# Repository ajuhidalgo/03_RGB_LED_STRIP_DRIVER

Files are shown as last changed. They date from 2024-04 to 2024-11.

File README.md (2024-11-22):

## Controlador de Tiras LED RGB con ESP32-C6-MINI
 

### Descripción
Este proyecto se centra en la creación de un controlador para tiras de LEDs RGB utilizando el microcontrolador **ESP32-C6-MINI**. El dispositivo está diseñado para ser compatible con **Google Home** y se conecta a través de **Wi-Fi**. El controlador permite seleccionar colores y efectos para las tiras LED.

### Componentes del Proyecto
1. **Circuito y PCB**: Diseñé el circuito y el PCB para el controlador utilizando **KiCad**. Puedes encontrar los esquemas y archivos Gerber en este repositorio.
2. **Carcasa**: Creé una carcasa en 3D para proteger el controlador con el programa **Fusion 360**. Los archivos STL y los detalles de impresión están disponibles en la carpeta de mecánica.
3. **Firmware**: El código fuente del firmware se encuentra en el repositorio. En la memoria del proyecto puedes obtener información acerca de la configuración.

### Características Clave
- **Microcontrolador**: Utilizamos el módulo **ESP32-C6-MINI** de Espressif Systems y transistores **mosfet** para controlar las tiras LED.
- **Interfaz de uso**: El dispositivo se controla a través del entorno **Google Home**. Permite la integración con la domótica del hogar, programar horarios de encendido o programar escenas. Esto lo conseguimos gracias al uso de la plataforma Sinric Pro.
- **Selección de Colores**: Los usuarios pueden elegir entre una amplia gama de colores para personalizar las tiras LED.

### Repositorio en GitHub
Puedes encontrar el código fuente, los esquemas, los archivos de Gerber, los archivos STL y más en este repositorio.

¡Buena suerte con tu proyecto! Si tienes alguna pregunta o necesitas más detalles, puedes ponerte en contacto conmigo.

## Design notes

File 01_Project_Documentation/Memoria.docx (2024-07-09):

DISEÑO DE UN CONTROLADOR IOT PARA TIRAS LED RGB

Autor: Juan Antonio Hidalgo Torres.

Fecha: 27/04/2024

# INDICE

# INDICE DE FIGURAS

# 1. INTRODUCCIÓN

En los últimos años, se ha incrementado considerablemente el número de dispositivos y objetos cotidianos que tienen acceso a internet, lo que ha dado lugar a lo que llamamos IoT. “Internet of things” es un concepto que hace referencia a la interconexión de dispositivos cotidianos a través de internet, lo que les permite comunicarse, recopilar datos o realizar acciones de forma inteligente en base a los datos recopilados. Todo esto tiene como principales beneficios la mejora en la eficiencia, la comodidad y la automatización en la vida cotidiana.

En la actualidad el IoT tiene muchísimas aplicaciones, como por ejemplo, en el campo de la salud, en el que cada vez se crean más dispositivos capaces de monitorizar constantes, llevar a cabo seguimientos de actividad y crear alertas. Por otro lado, en el mundo de la agricultura tambien podemos encontrar aplicaciones, como el monitoreo de cultivos, el riego automático o el seguimiento de ganado. Además, existen muchos más ámbitos a los que ha llegado el IoT, pero en concreto, es en la domótica donde más se ha desarrollado. Esto se debe a que ha permitido controlar de forma inteligente todo tipo de dispositivos del hogar, como cerraduras, persianas, luces, termostatos, cámaras de seguridad y todo tipo de electrodomésticos.

En dispositivos como luces, y aún más en luces RGB, tener conexión y control a través de internet nos puede aportar numerosos aspectos positivos. En concreto, podremos programar horarios de encendido y apagado, programar diferentes escenas, controlar los colores, prescindir de mandos a distancia o actuar con comandos de voz con la ayuda de plataformas como Home Assistant.

Es por esto, por lo que en este proyecto, crearemos un dispositivo capaz de llevar a cabo todas las acciones anteriormente descritas, y que sea compatible con el entorno de Google Home.

Este proyecto surge a partir de la iniciativa personal de desarrollar un proyecto “open source”, con la intención de compartir de forma libre el trabajo realizado. Y, de este modo, devolver a la comunidad de hardware libre parte del conocimiento adquirido a lo largo de los años. Por otra parte, surge de la meta personal de crear un dispositivo que permita controlar las luces decorativas de una forma sencilla, sin mandos a distancia y conectado a internet. Aunque ya existen dispositivos como este en el mercado con un precio accesible, creo que el valor de un proyecto de estas características reside en el aprendizaje que se puede lograr en el proceso y en la satisfacción personal de crear un producto desde cero.

# 2. OBJETIVOS DEL PROYECTO

Como objetivo principal del proyecto, planteamos crear un dispositivo que permita controlar tiras led RGB de forma remota y a través de internet.

Para el desarrollo del objetivo principal descrito anteriormente, se plantean los siguientes objetivos secundarios:

- Diseño y fabricación de un PCB que permita controlar la tira led RGB. Nos permitirá el encendido y el apagado de la tira, modificar el color y modificar el brillo de la luz que emite. Además, tendrá la capacidad de conectarse a internet mediante Wi-Fi.
- Diseño y fabricación de una carcasa para envolver el PCB.
- Desarrollo del software del dispositivo.
- Integración del dispositivo con el entorno de Google Home.

# 3. DESCRIPCIÓN DEL SISTEMA

Como se puede ver en la siguiente imagen, el sistema completo está formado por un total de tres bloques principales: Google home, Sinric Pro, el circuito físico del controlador o PCB, y el firmware encargado de controlar a este.

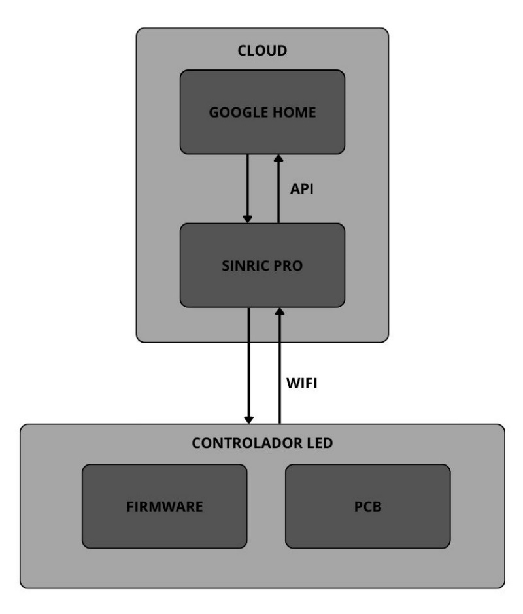
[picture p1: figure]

## 3.1 PCB.

Por un lado, encontramos el PCB objeto de diseño en este proyecto, en el que encontraremos un microcontrolador, los transistores necesarios para controlar cada canal de la tira, y los componentes necesarios para la fase de alimentación:

- Microcontrolador ESP32-C6 Mini para un procesamiento potente con un reducido tamaño y bajo consumo. Además, nos permite la conexión Wi-Fi y Bluetooth.
- Tres transistores MOSFETs FDD8880 para un control preciso de cada canal de las tiras de LED.
- Regulador de voltaje AMS1117CD para convertir la alimentación de entrada de 12V a un voltaje estable de 3.3V para el ESP32-C6 Mini y otros componentes.
- Componentes pasivos adicionales para completar el circuito y garantizar un funcionamiento óptimo.

El ESP32-C6 Mini envía a los MOSFETs señales PWM (Pulse Width Modulation) para modular la intensidad de cada uno de los tres canales de las tiras de LED con precisión. El regulador de voltaje asegura un voltaje estable 3.3V para el ESP32-C6 Mini y el resto de las componentes del circuito lógico.

## 3.2 FIRMWARE.

El firmware programado para el microcontrolador ESP32-C6 Mini, usando el framework de Arduino y el entorno de PlatformIO en Visual Studio Code, permite la gestión del hardware de potencia. Además, se encarga de las comunicaciones con el intermediario Sinric Pro y el ecosistema de domótica Google Home.

En concreto, el firmware se encarga de las siguientes tareas

- Recibir comandos de la aplicación Google Home a través de Sinric Pro.
- Interpretar los comandos de forma precisa y generar las señales PWM adecuadas para controlar los MOSFETs.
- Monitorear el estado de las tiras de LED.
- Enviar información de estado y actualizaciones a la aplicación Google Home, a través de Sinric Pro, para mantener una sincronización completa.

## 3.3 SINRIC PRO.

Sinric Pro es una plataforma de IoT (Internet de las Cosas) que permite conectar dispositivos IoT a los asistentes de voz Alexa y Google Home. Actúa como intermediario entre la aplicación Google Home y el firmware del ESP32-C6 Mini, facilitando la comunicación entre ambos. De esta forma, no será necesario programar una API que lleve a cabo este trabajo.

Como ventajas principales encontramos las siguientes:

- Conexión segura y robusta: Utiliza una conexión directa con los servidores de Amazon y Google para una experiencia más estable.
- Compatibilidad amplia: Soporta todos los tipos de dispositivos IoT, incluyendo luces, interruptores, cerraduras, termostatos, sensores, etc.
- Fácil de usar: Configuración sencilla y gratuita a través de una interfaz web de usuario.
- Desarrollo flexible: Ofrece bibliotecas Python, C++ y Arduino con ejemplos para crear aplicaciones IoT personalizadas.

## 3.4 GOOGLE HOME.

La aplicación Google Home ofrece una interfaz de usuario intuitiva y fácil de usar para controlar las tiras de LED de forma remota desde una app o desde la web. De este modo, no tendremos que llevar a cabo el trabajo de crear nuestra propia interfaz, y podremos aprovechar el sistema de Google. Esto nos permite una mayor usabilidad e integración con el sistema domótico ya existente.

La interfaz de usuario nos facilita las siguientes acciones:

- Encender y apagar las luces de forma simple desde la app y con comandos de voz a través del asistente.
- Ajustar la intensidad de las luces.
- Seleccionar el color de las luces.
- Crear escenas de iluminación personalizadas.

# 4. DISEÑO DEL SISTEMA

# 5. PROTOTIPO

# 6. RESULTADOS

# 7. CONCLUSIONES

Diseño de un controlador IoT para tiras led RGB Juan Antonio Hidalgo Torres

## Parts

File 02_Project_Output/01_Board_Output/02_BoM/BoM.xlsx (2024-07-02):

Manufacter | Manufacter Part Number | Description | References | Quantity | URL
Samsung Electro-Mechanics | CL10E104KC8VPNC | CAP CER 100NF 100V X8L 0603 | C1 | 2 | https://www.digikey.es/es/products/detail/samsung-electro-mechanics/CL10E104KC8VPNC/20498486
YAGEO | CC0603KRX7R7BB105 | CAP CER 1UF 16V X7R 0603 | C2, C3 | 2 | https://www.digikey.es/es/products/detail/yageo/CC0603KRX7R7BB105/2833611
YAGEO | RC0603FR-0710KL | RES 10K OHM 1% 1/10W 0603 | R1, R2, R3, R4, R5, R6 | 7 | https://www.digikey.es/es/products/detail/yageo/RC0603FR-0710KL/726880
Vishay General Semiconductor | DF04S-E3/77 | BRIDGE RECT 1PHASE 400V 1A DFS | D1 | 1 | https://www.digikey.es/es/products/detail/vishay-general-semiconductor-diodes-division/DF04S-E3-77/2143841
Espressif Systems | ESP32-C6-MINI-1-N4 | RF TXRX MODULE BT PCB TRACE SMD | IC1 | 1 | https://www.digikey.es/es/products/detail/espressif-systems/ESP32-C6-MINI-1-N4/17885796
UMW | AMS1117CD-3.3 | IC LDO REG 3.3V 1A TO252 | U1 | 1 | https://www.digikey.es/es/products/detail/umw/AMS1117CD-3-3/17635272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
Onsemi | FDD8880 | MOSFET N-CH 30V 13A/58A TO252AA | Q1, Q2, Q3 | 3 | https://www.digikey.es/es/products/detail/onsemi/FDD8880/979930
Omron Electronics | B3U-1000P | SWITCH TACTILE SPST-NO 0.05A 12V | S1, S2 | 2 | https://www.digikey.es/es/products/detail/omron-electronics-inc-emc-div/B3U-1000P/1534338
CUI Devices | PJ-102A | CONN PWR JACK 2X5.5MM SOLDER | J1 | 1 | https://www.digikey.es/es/products/detail/cui-devices/PJ-102A/275425
JST Sales America | S4B-XH-A | CONN HEADER R/A 4POS 2.5MM | J2 | 1 | https://www.digikey.es/es/products/detail/jst-sales-america-inc/S4B-XH-A/1651041
Würth Elektronik | 61300411121 | CONN HEADER VERT 4POS 2.54MM | J3 | 1 | https://www.digikey.es/es/products/detail/w%C3%BCrth-elektronik/61300411121/4846827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

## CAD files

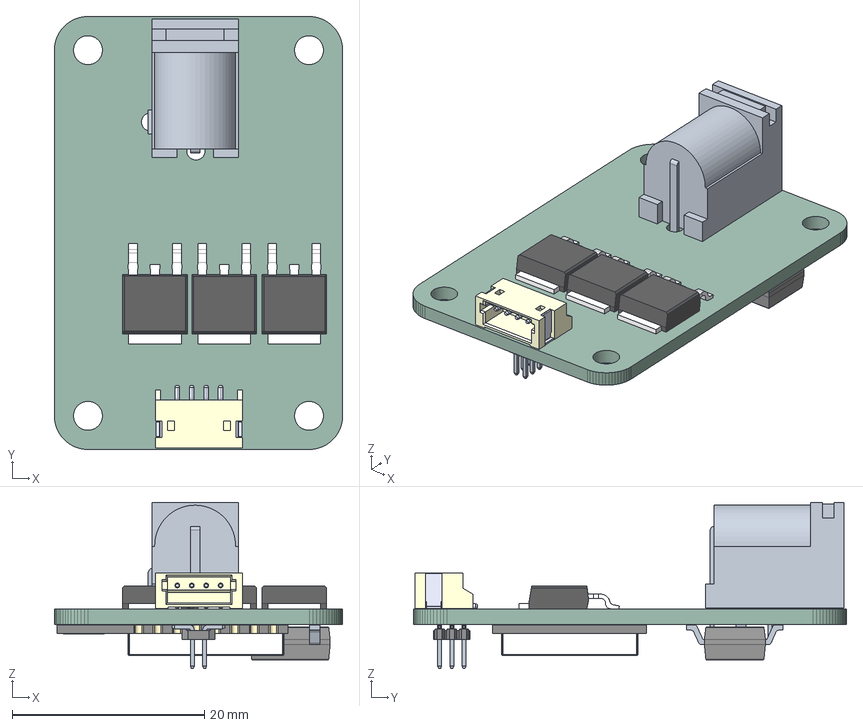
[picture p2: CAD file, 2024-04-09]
02_Project_Output/01_Board_Output/05_ExportSTEP/DriverRGB_v2.step
30.0 x 45.0 x 17.3 mm
DriverRGB_v2 PCB

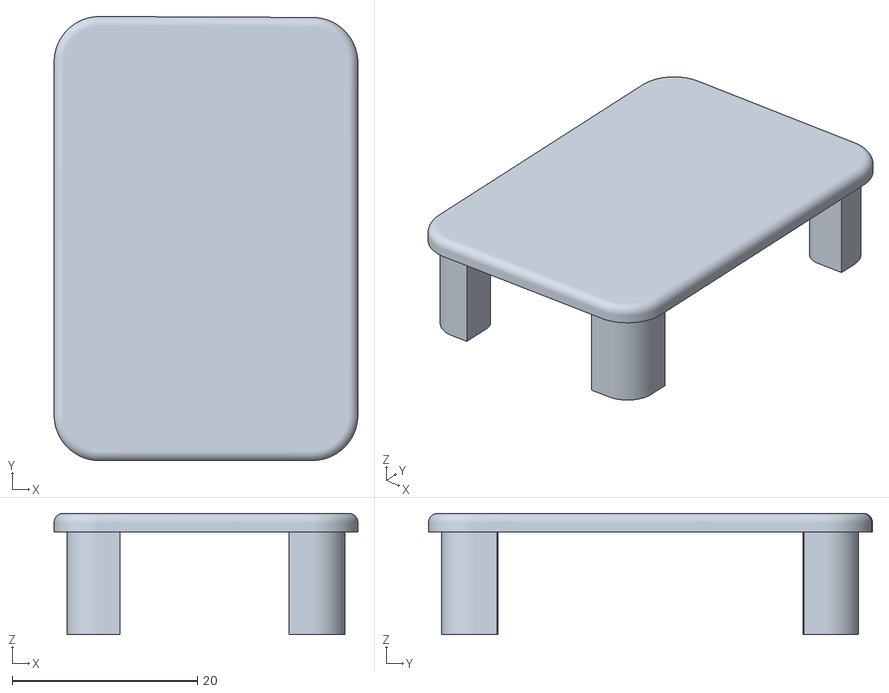
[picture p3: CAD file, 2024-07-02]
02_Project_Output/02_Mechanical_Ouput/Driver_Case_Top.stl
32.8 x 47.9 x 13.1

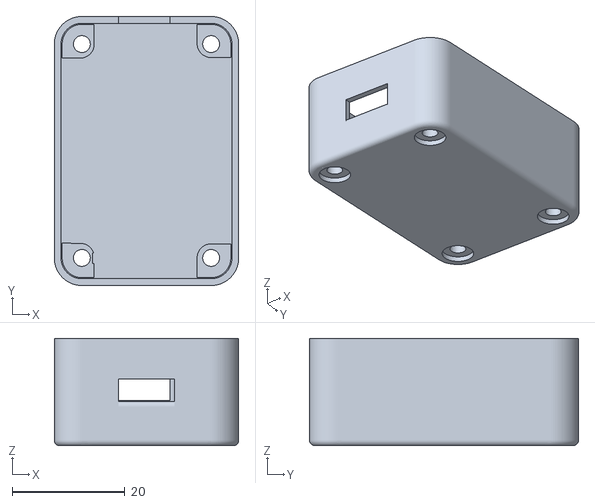
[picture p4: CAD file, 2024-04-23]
05_Mechanical_Desing/Driver_Case_Bottom.stl
32.8 x 47.8 x 19.1

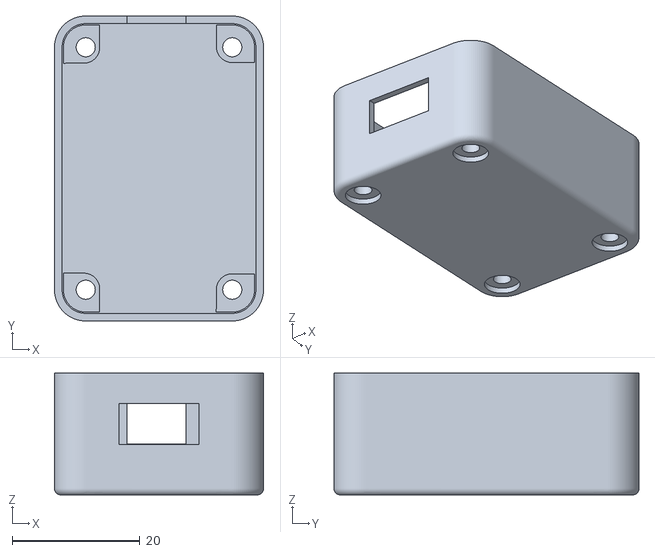
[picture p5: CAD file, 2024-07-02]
02_Project_Output/02_Mechanical_Ouput/Driver_Case_Bottom.stl
32.8 x 47.8 x 19.1

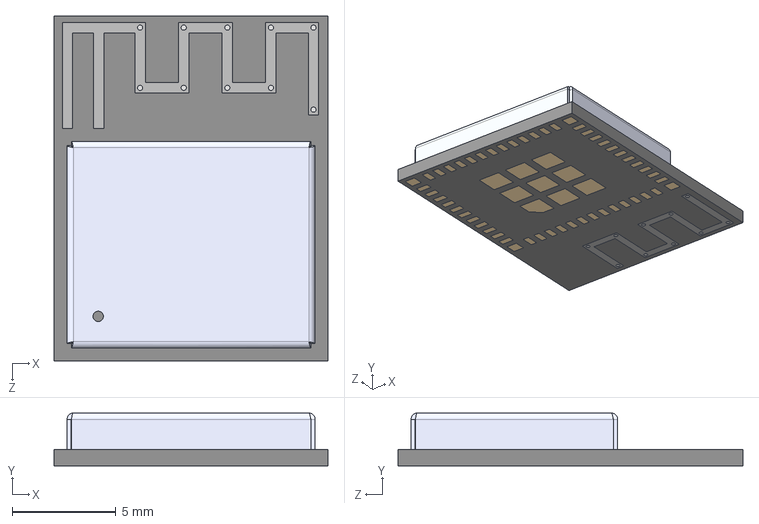
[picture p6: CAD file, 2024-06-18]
03_Boards/02_Libraries/03_3D/ESP32-C6-MINI-1-N4.STEP
13.2 x 2.55 x 16.6 mm

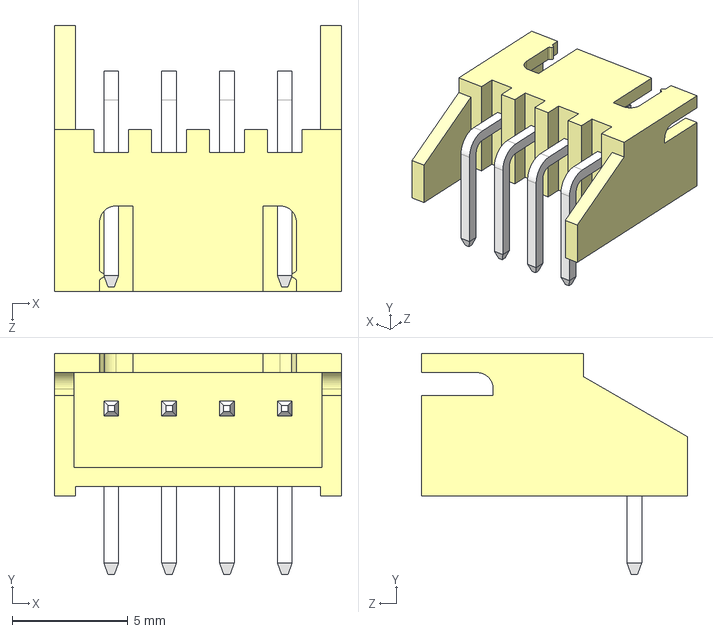
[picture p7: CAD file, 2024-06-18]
03_Boards/02_Libraries/03_3D/S4B-XH-A_LF__SN_.step
12.4 x 9.55 x 11.5 mm

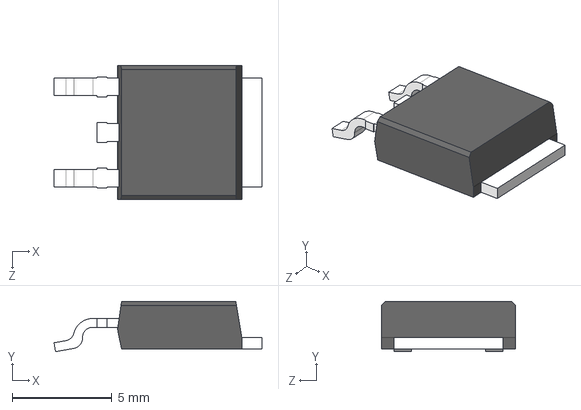
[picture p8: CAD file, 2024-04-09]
03_Boards/02_Libraries/03_3D/FDD8880.stp
10.4 x 2.52 x 6.73 mm

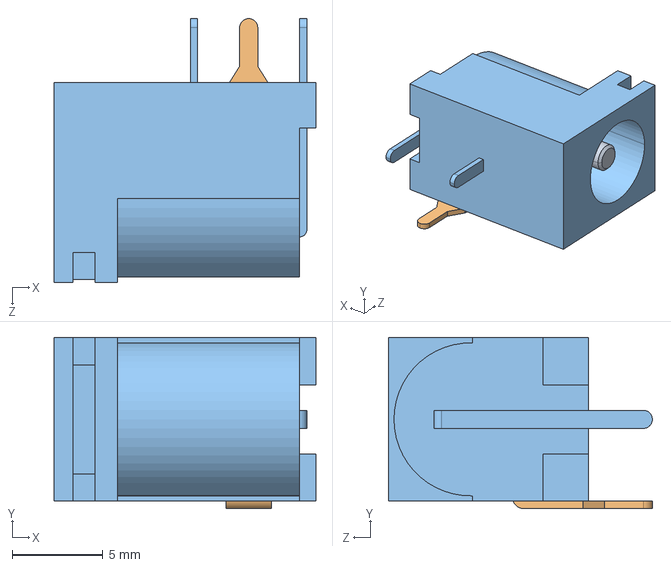
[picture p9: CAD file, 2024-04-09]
03_Boards/02_Libraries/03_3D/PJ-102A.stp
14.4 x 9.40 x 14.5 mm

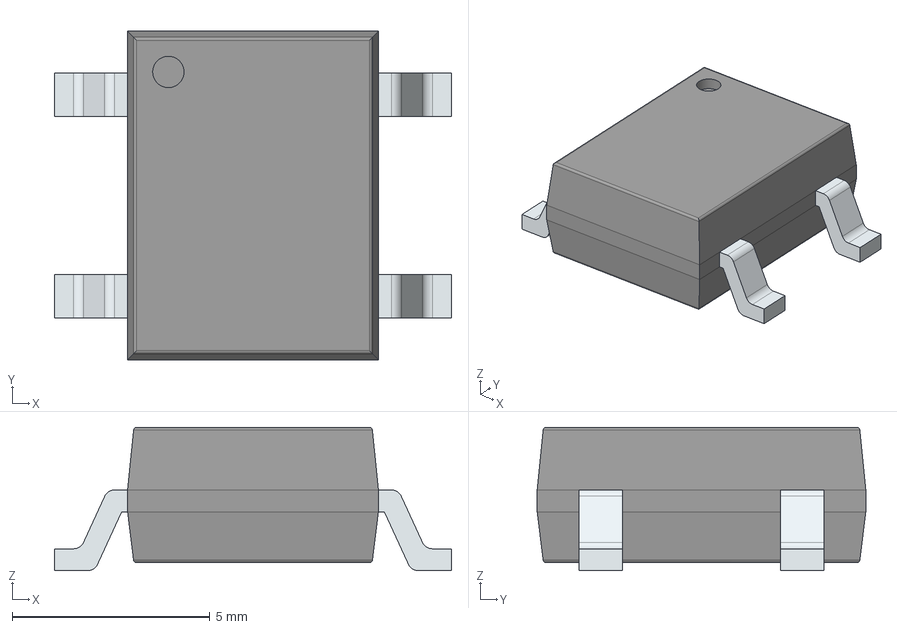
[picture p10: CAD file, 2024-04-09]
03_Boards/02_Libraries/03_3D/DF04S-E3_77.stp
10.1 x 8.32 x 3.63 mm
PinsArrayLR

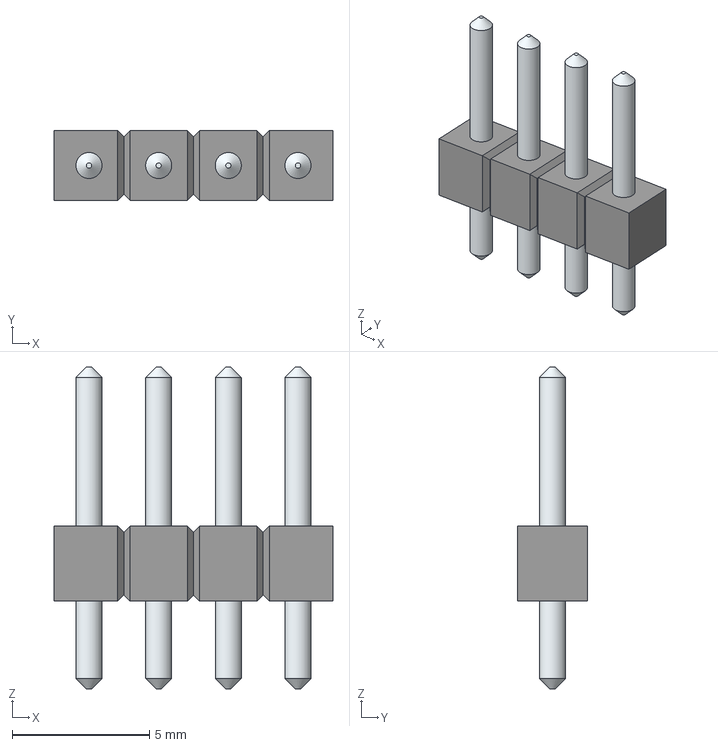
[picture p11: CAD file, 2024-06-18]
03_Boards/02_Libraries/03_3D/61300411121.stp
10.2 x 2.54 x 11.7 mm
LeadsArray

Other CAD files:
05_Mechanical_Desing/Driver_Case_Top.stl

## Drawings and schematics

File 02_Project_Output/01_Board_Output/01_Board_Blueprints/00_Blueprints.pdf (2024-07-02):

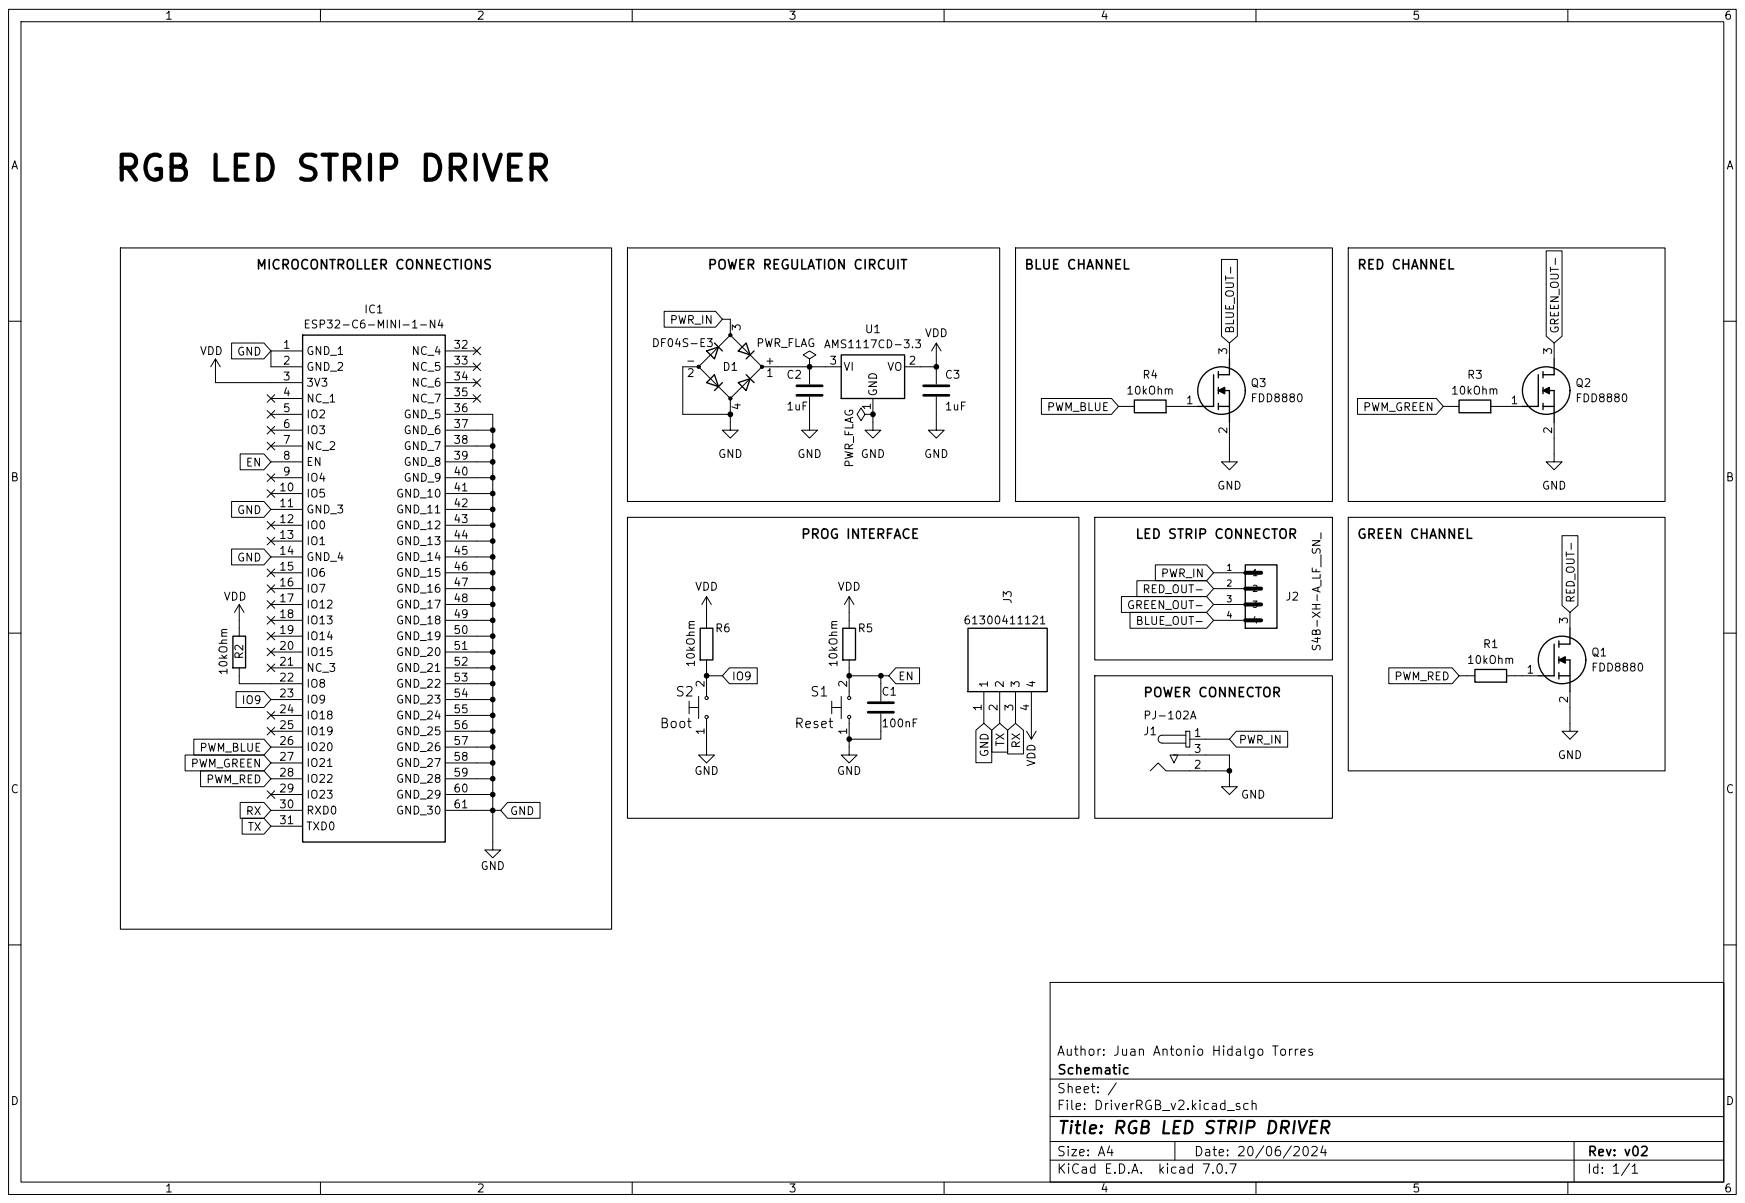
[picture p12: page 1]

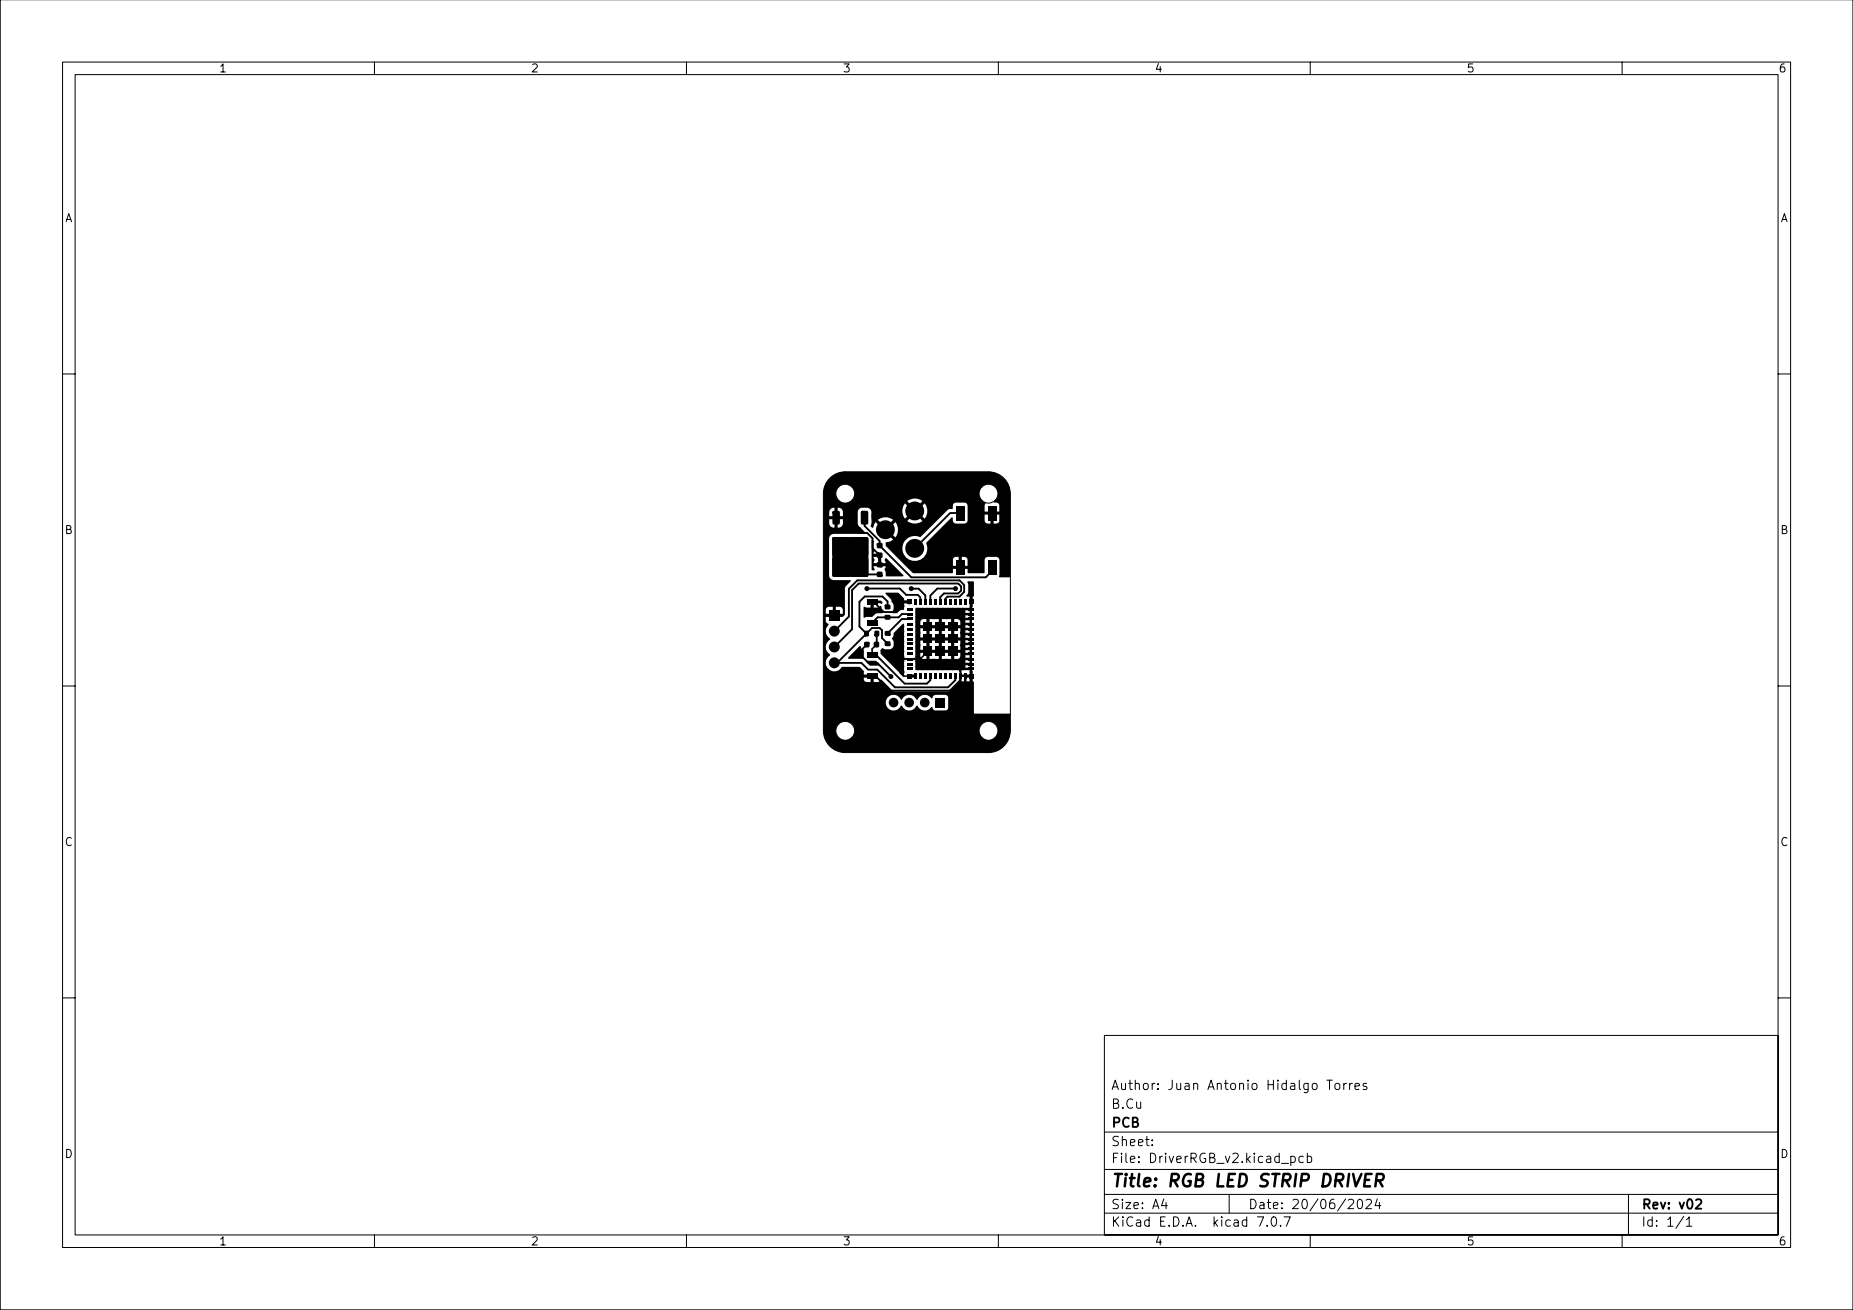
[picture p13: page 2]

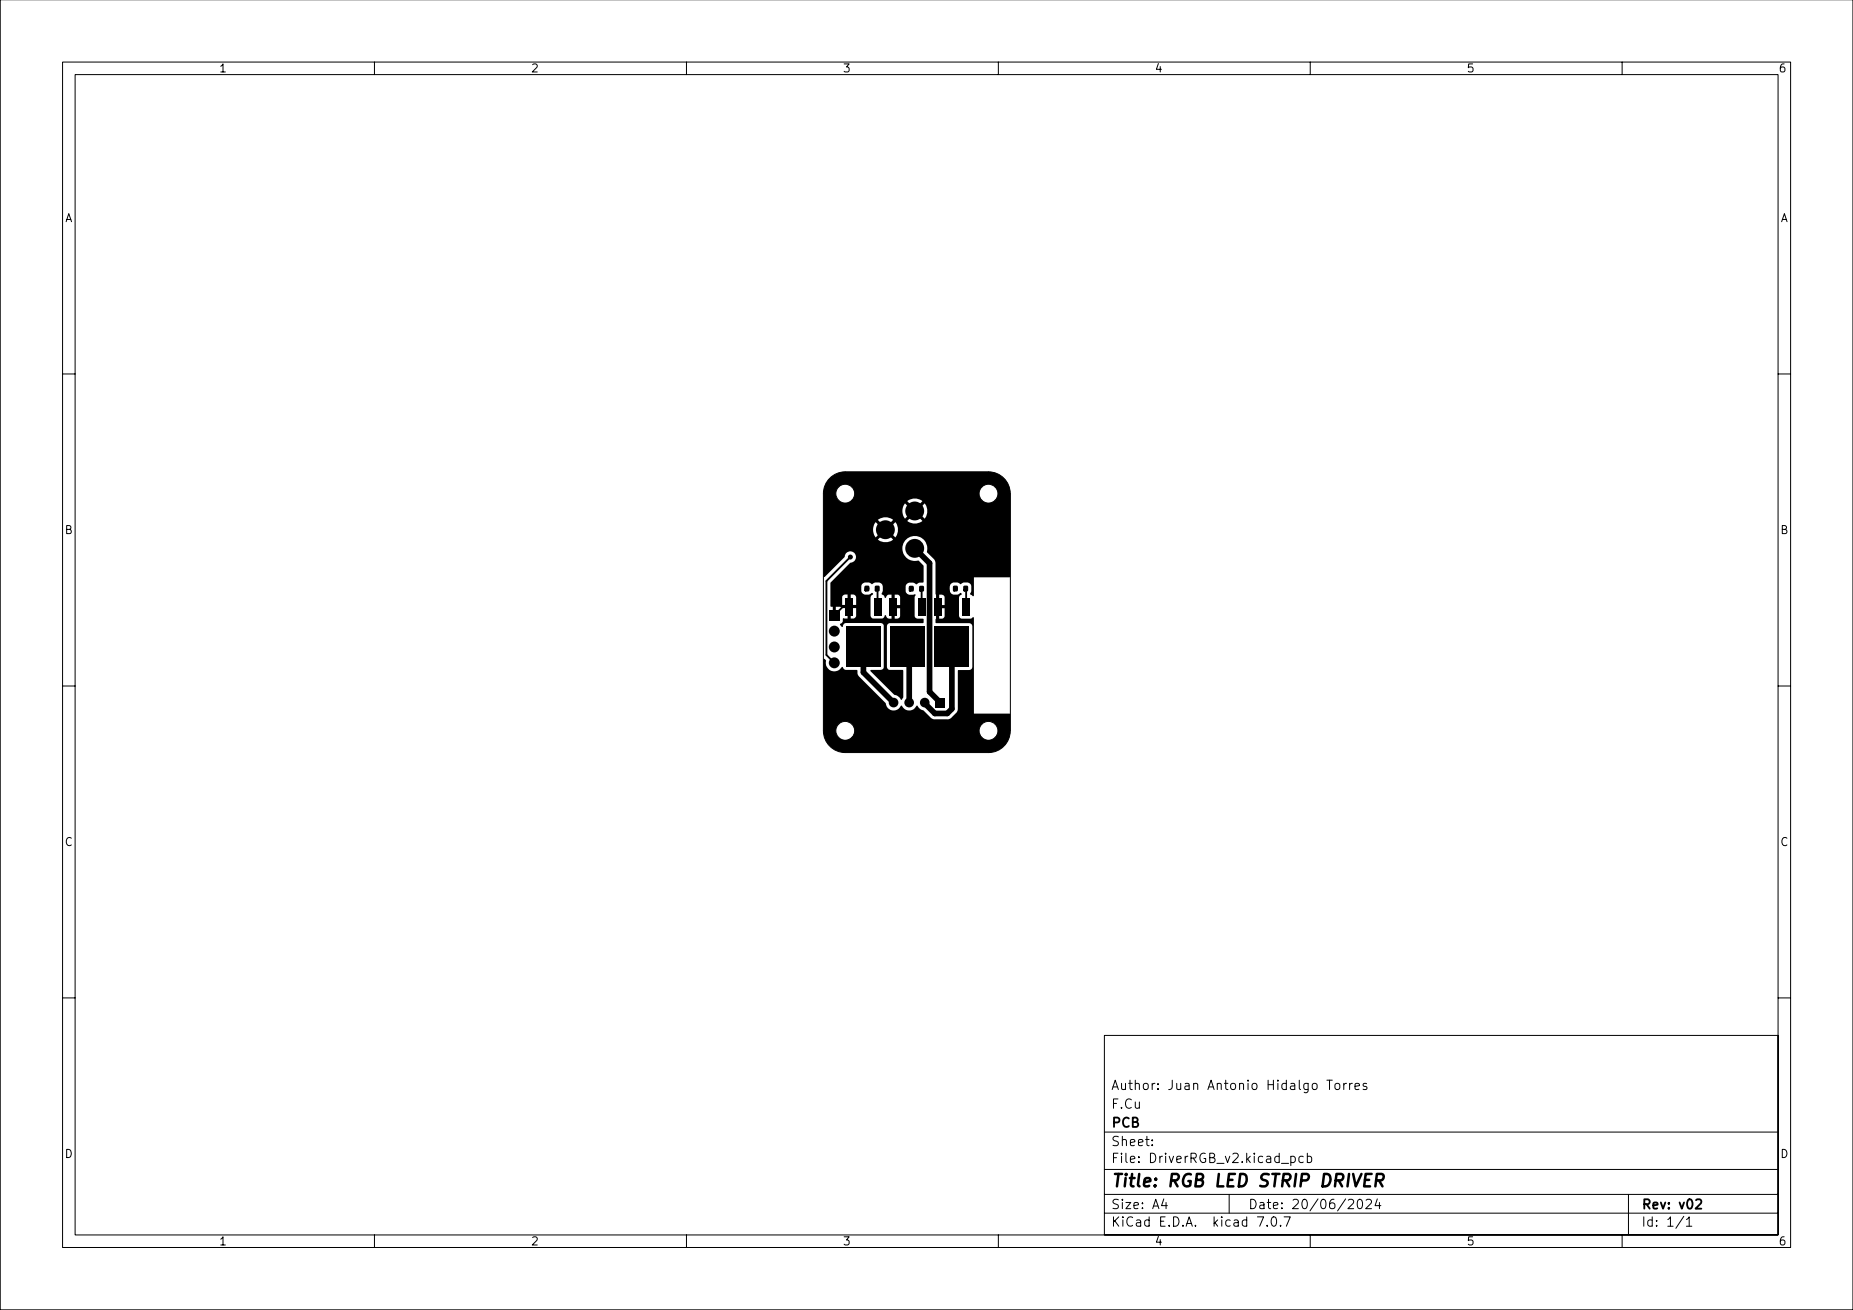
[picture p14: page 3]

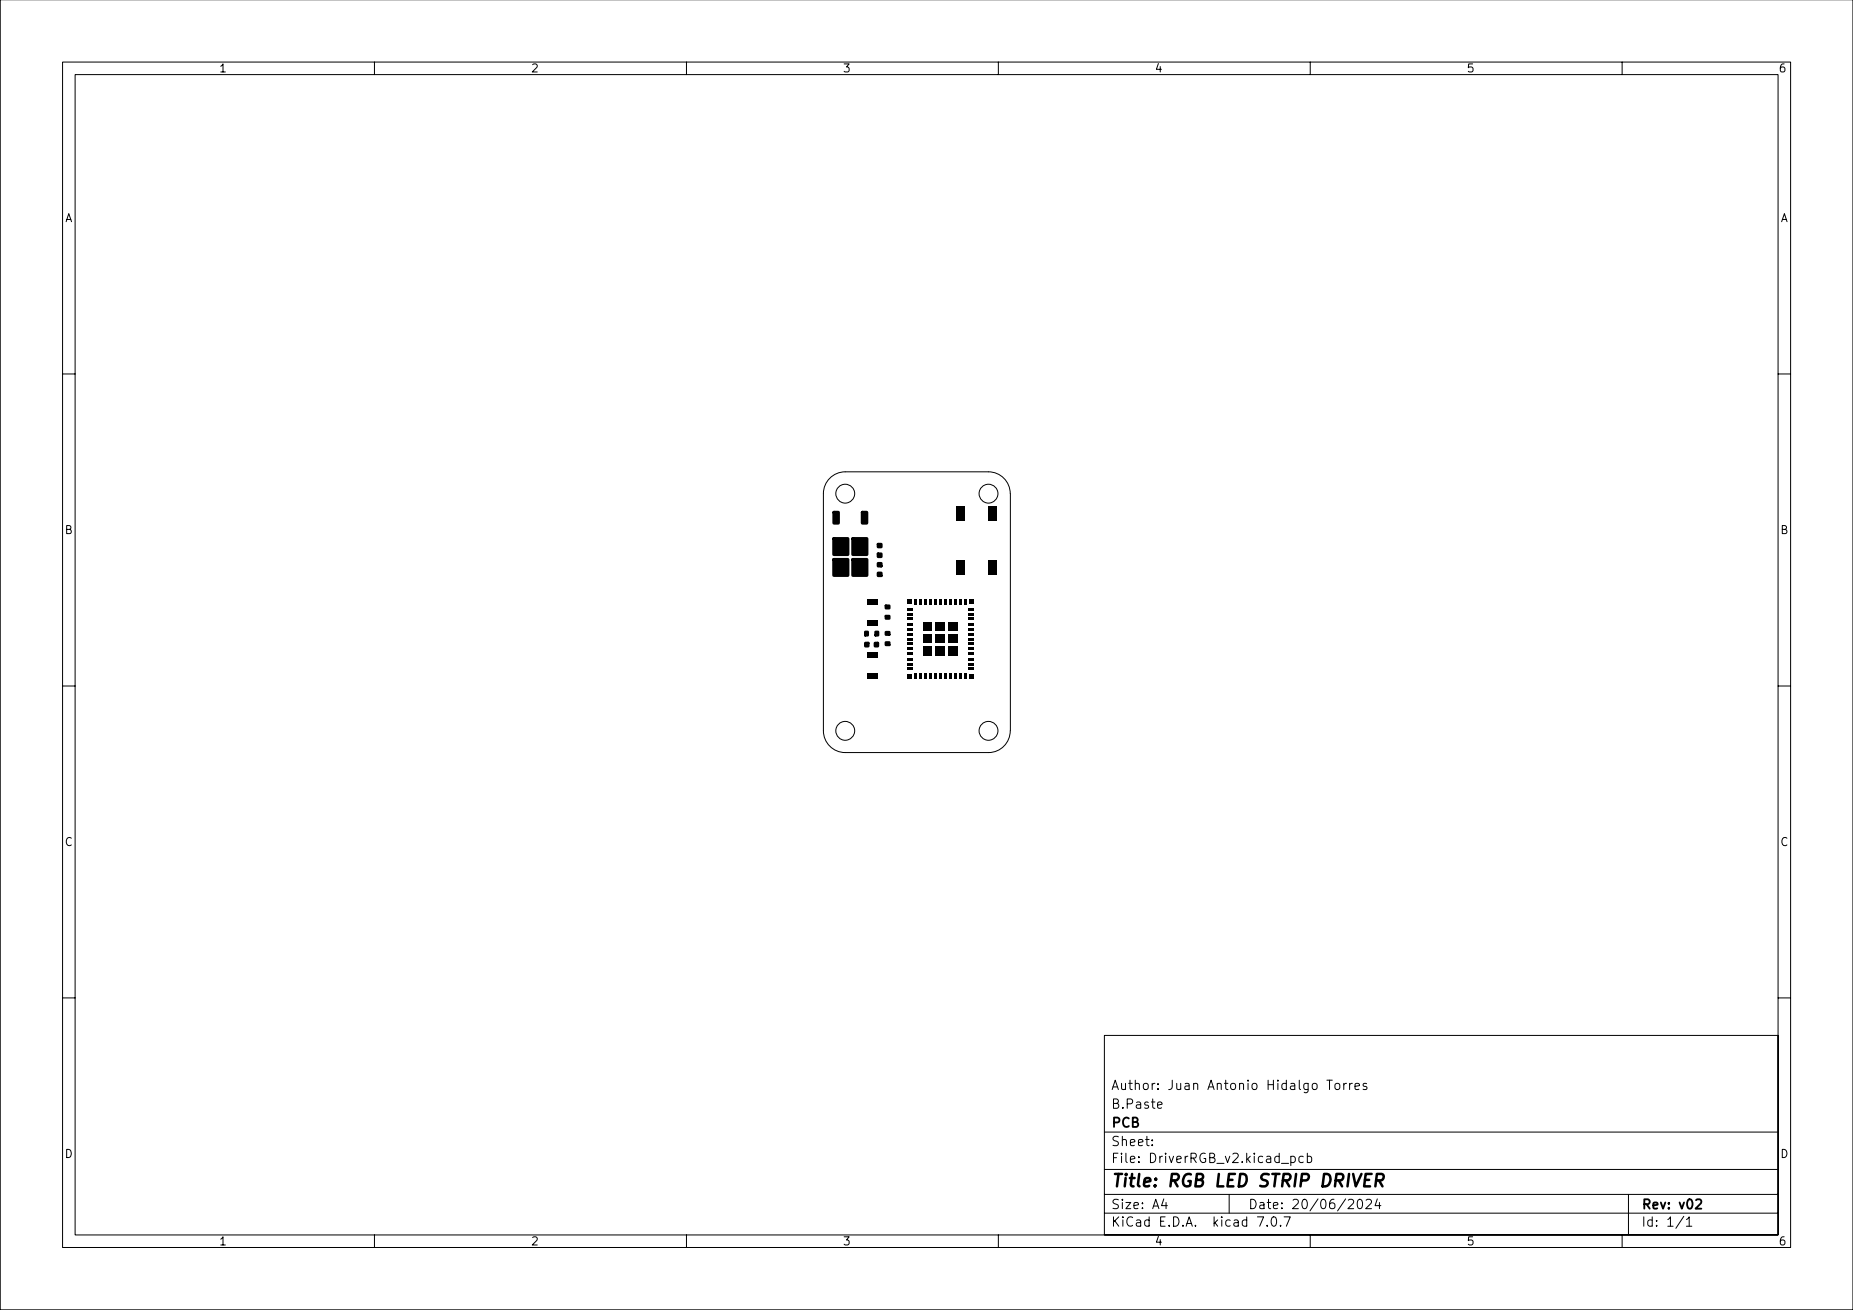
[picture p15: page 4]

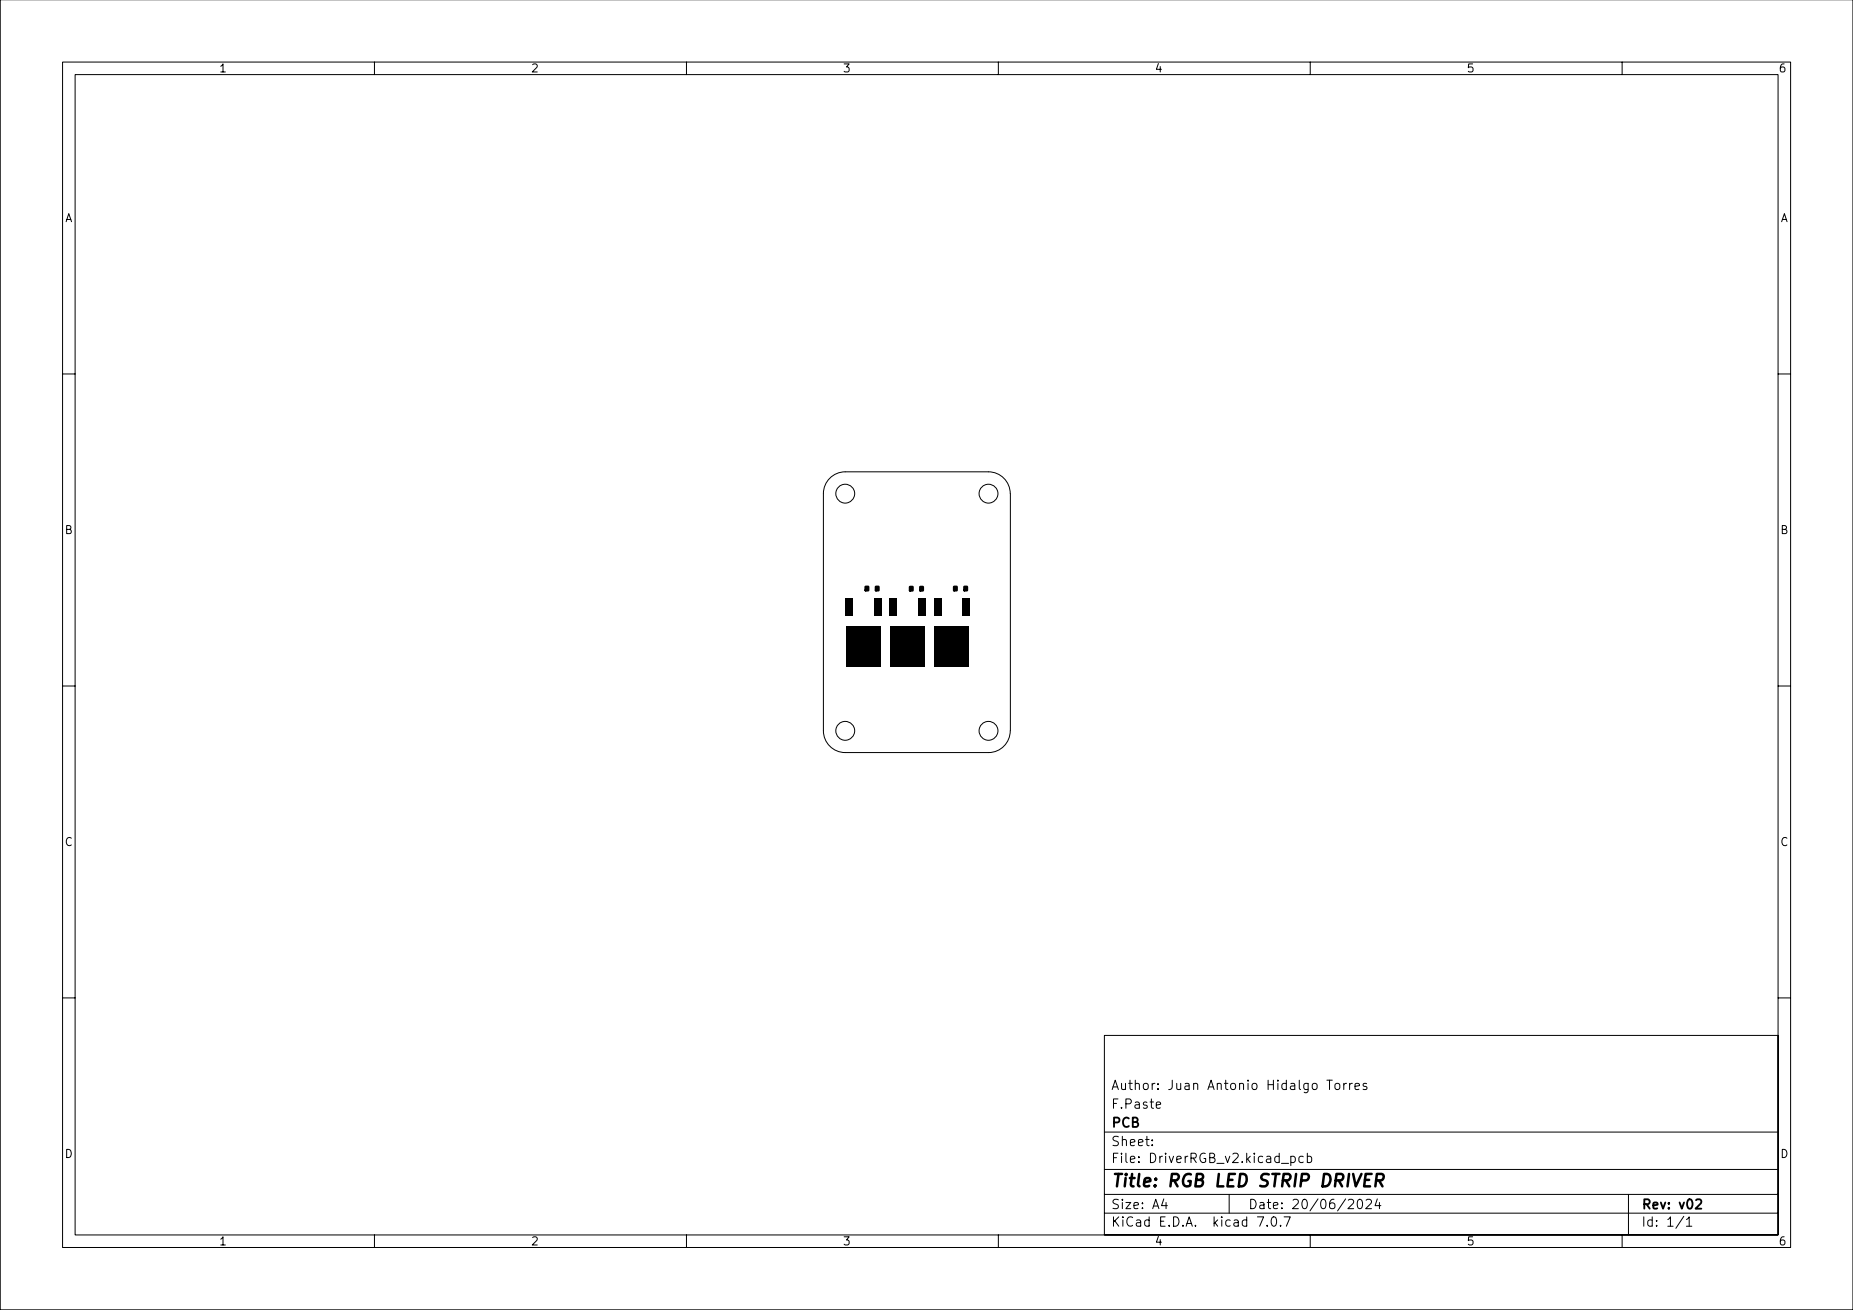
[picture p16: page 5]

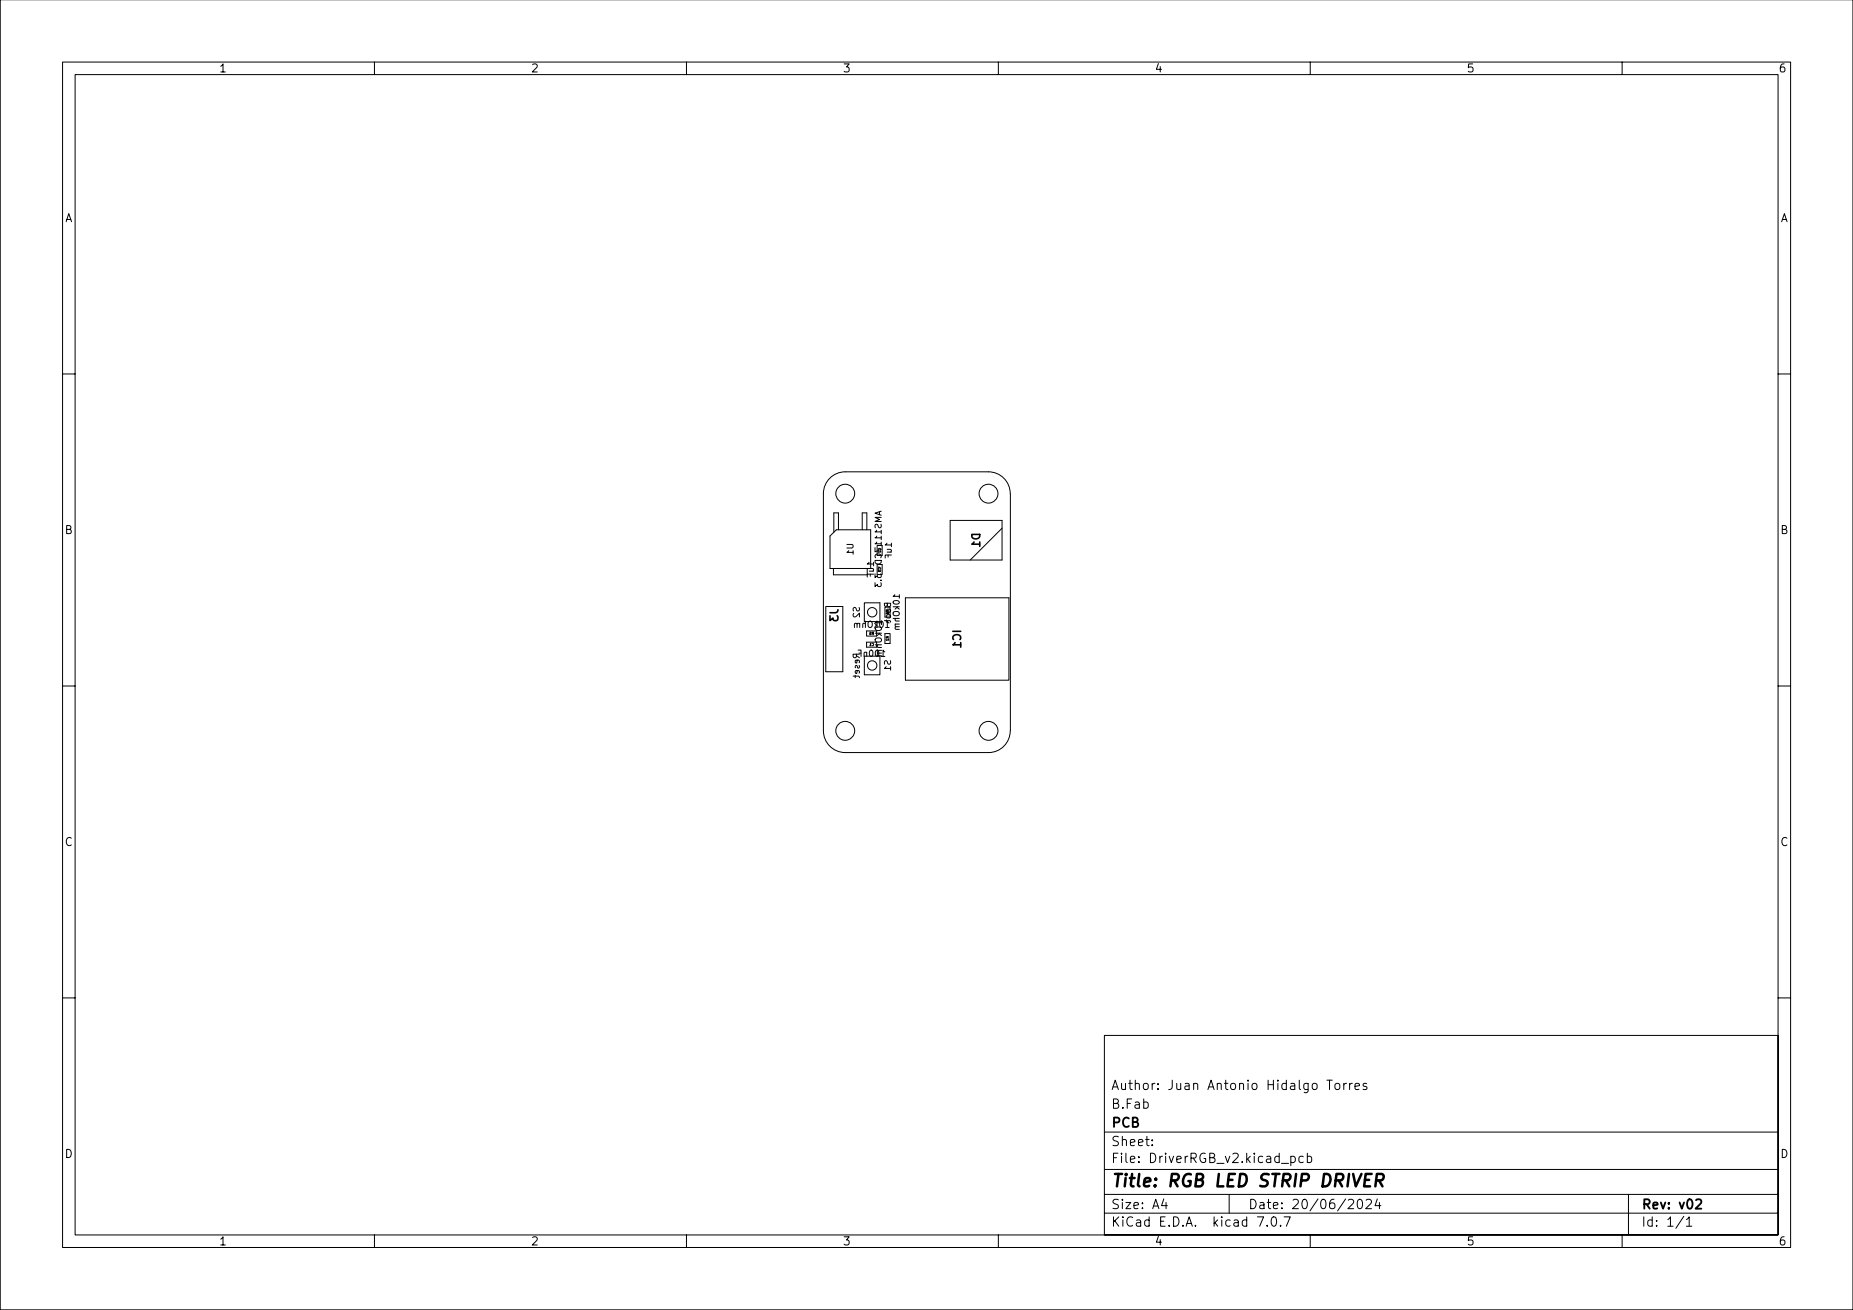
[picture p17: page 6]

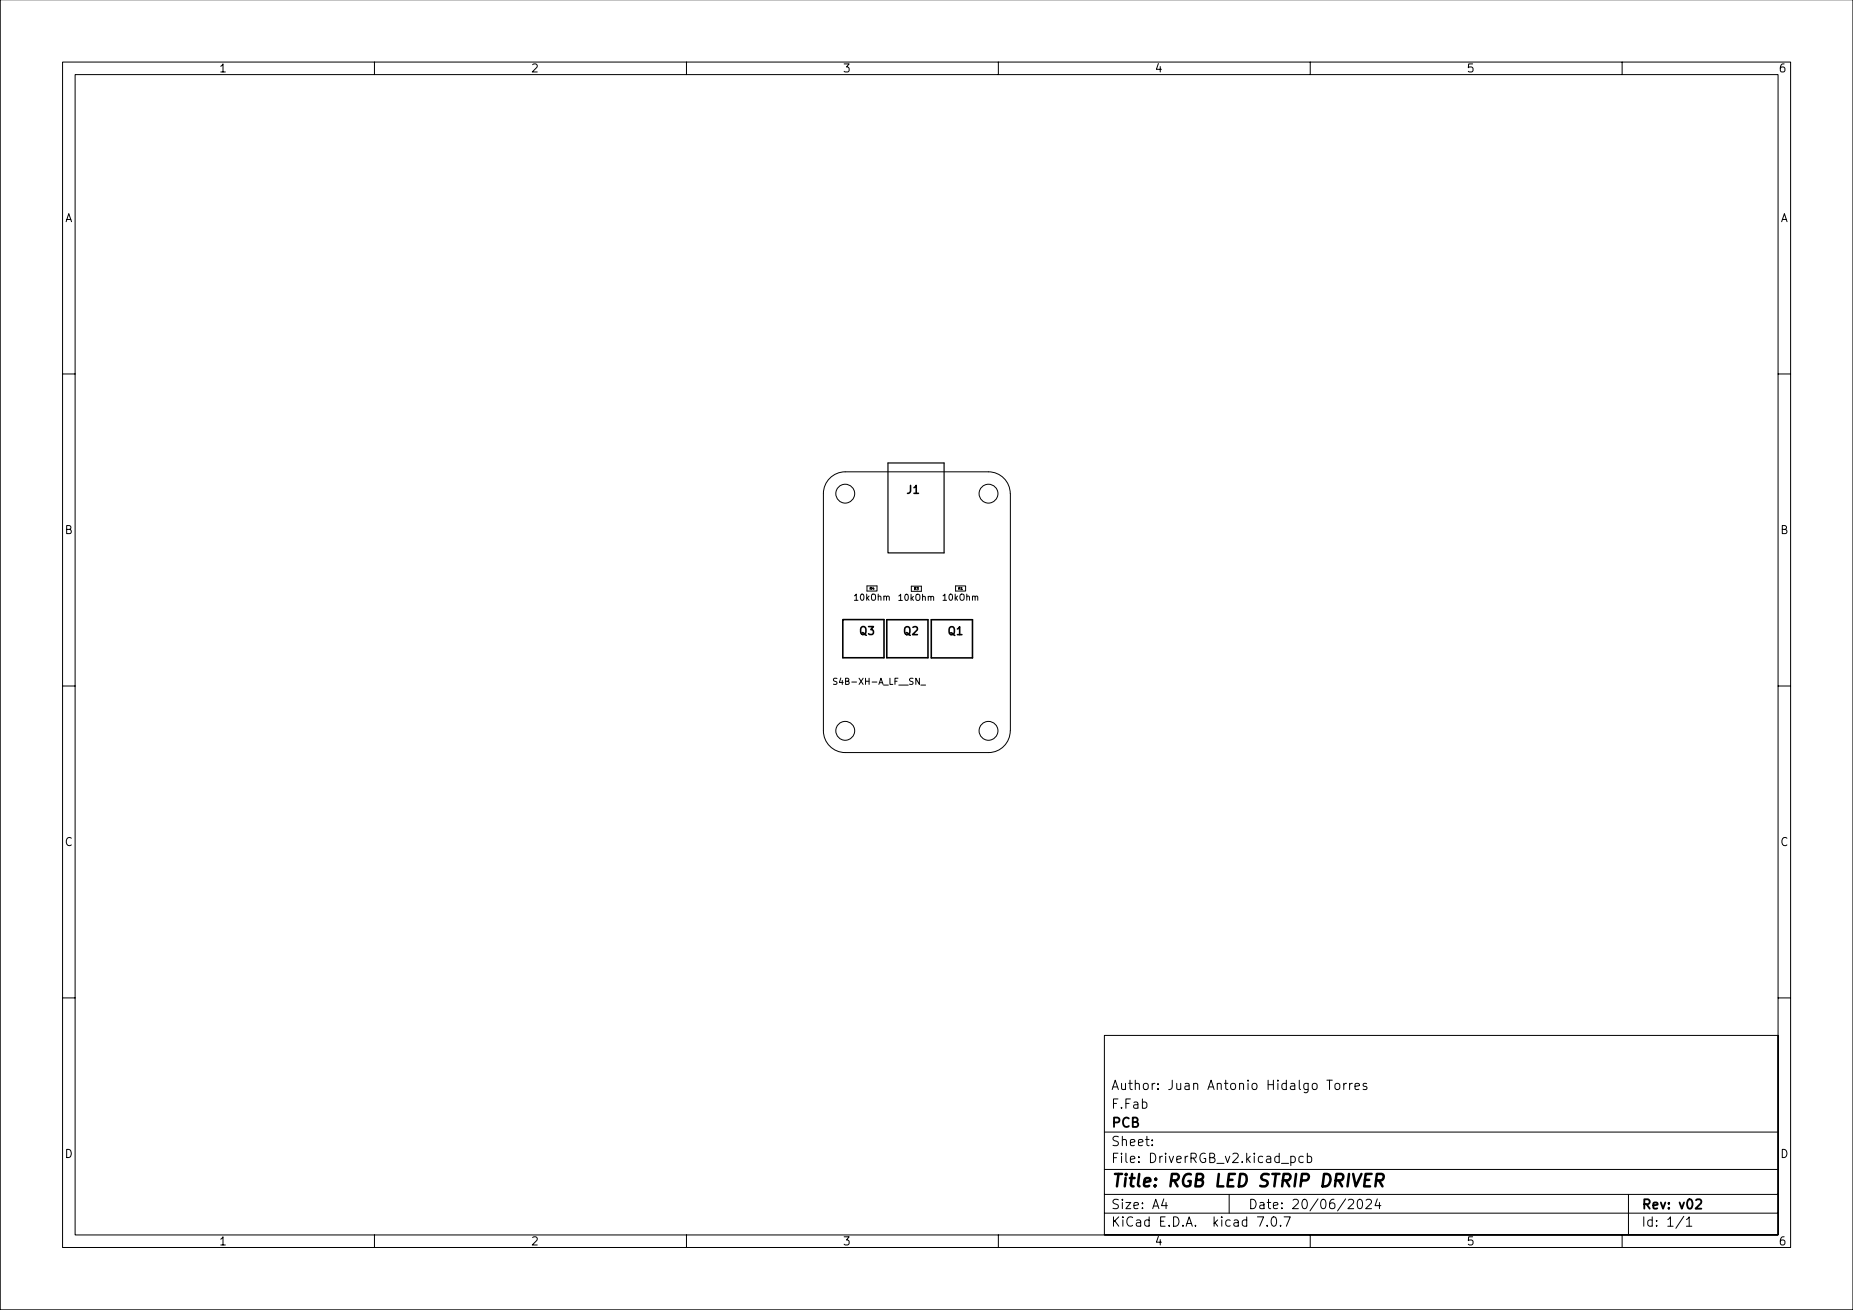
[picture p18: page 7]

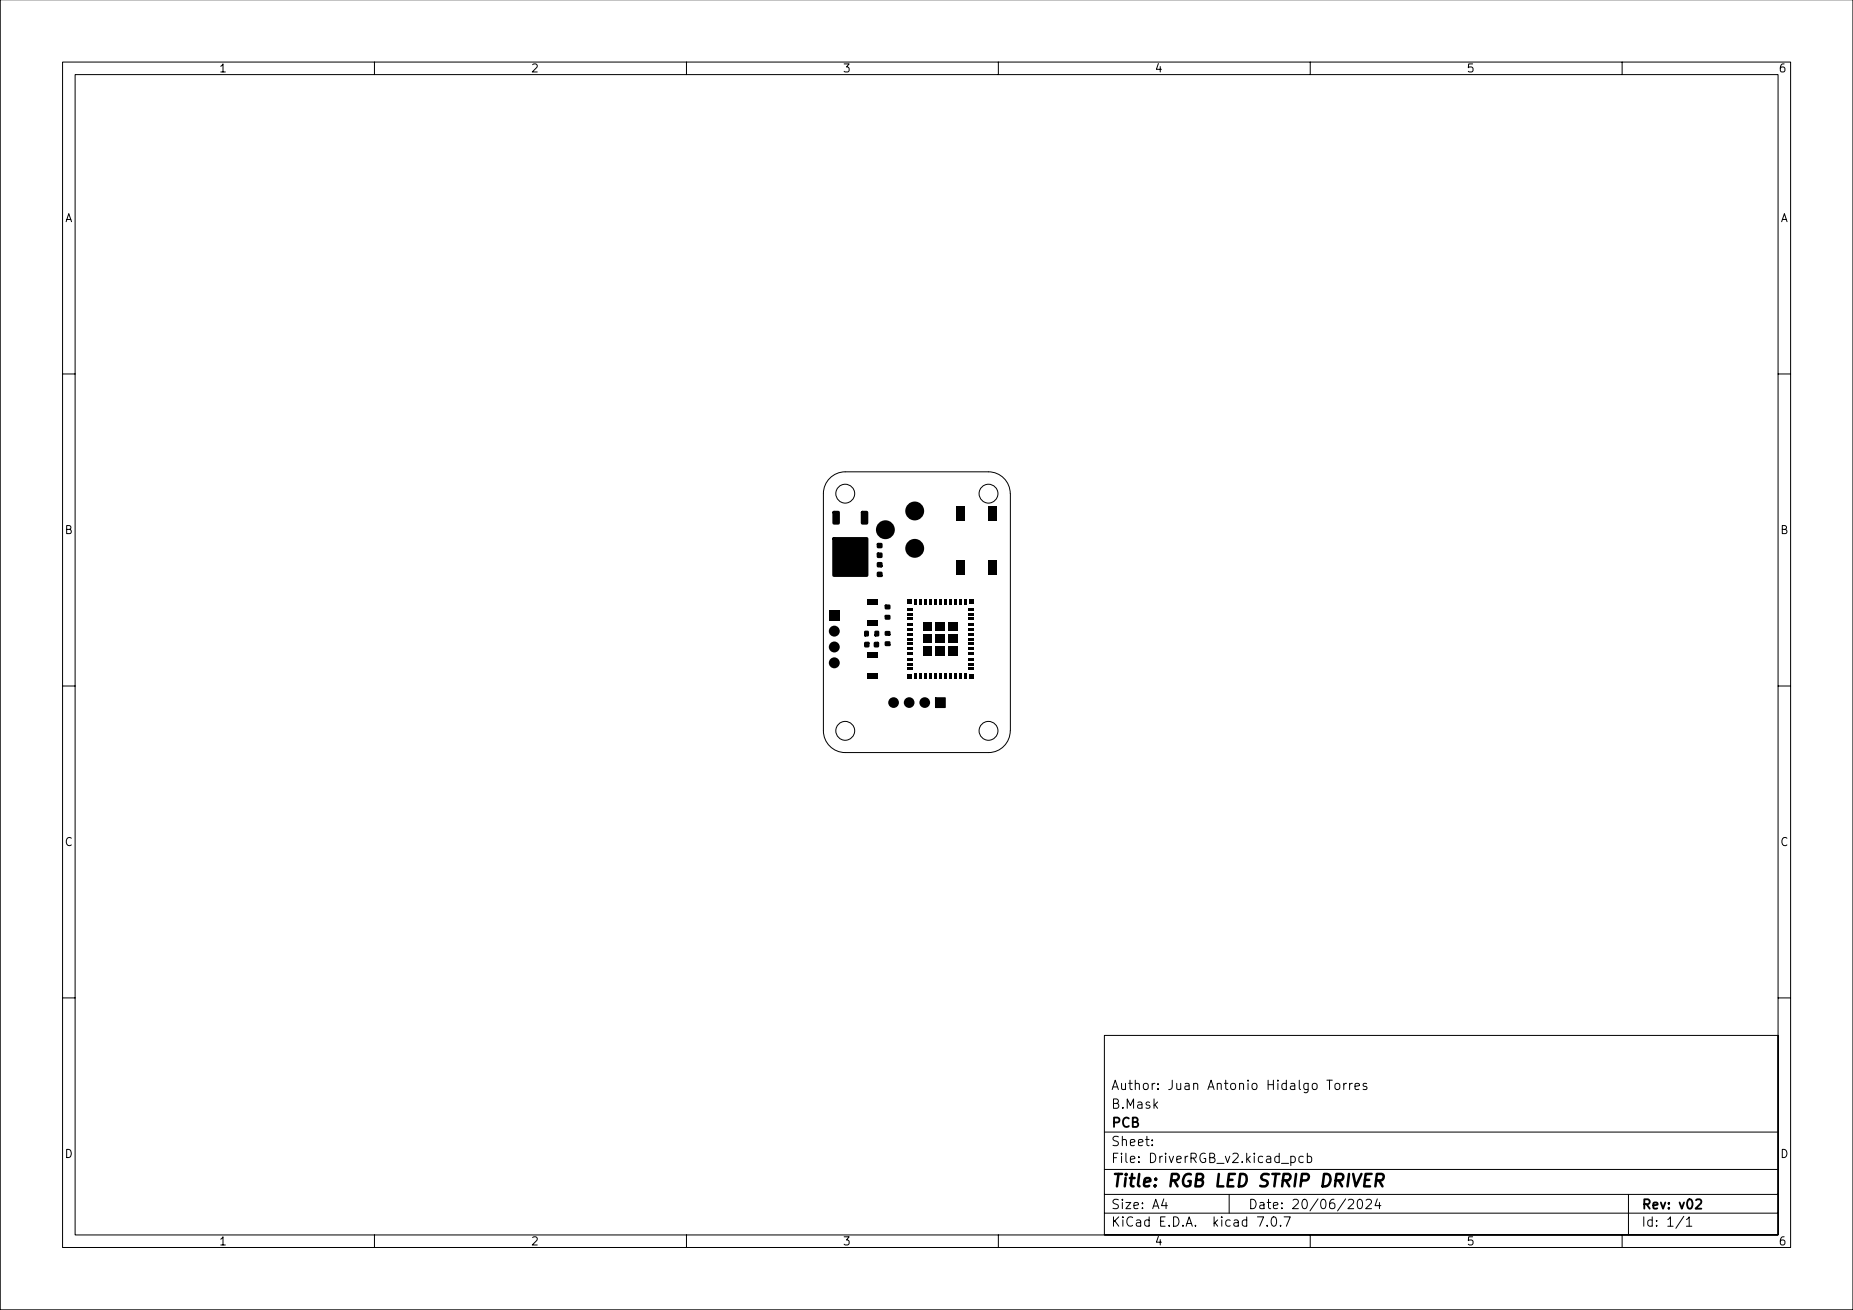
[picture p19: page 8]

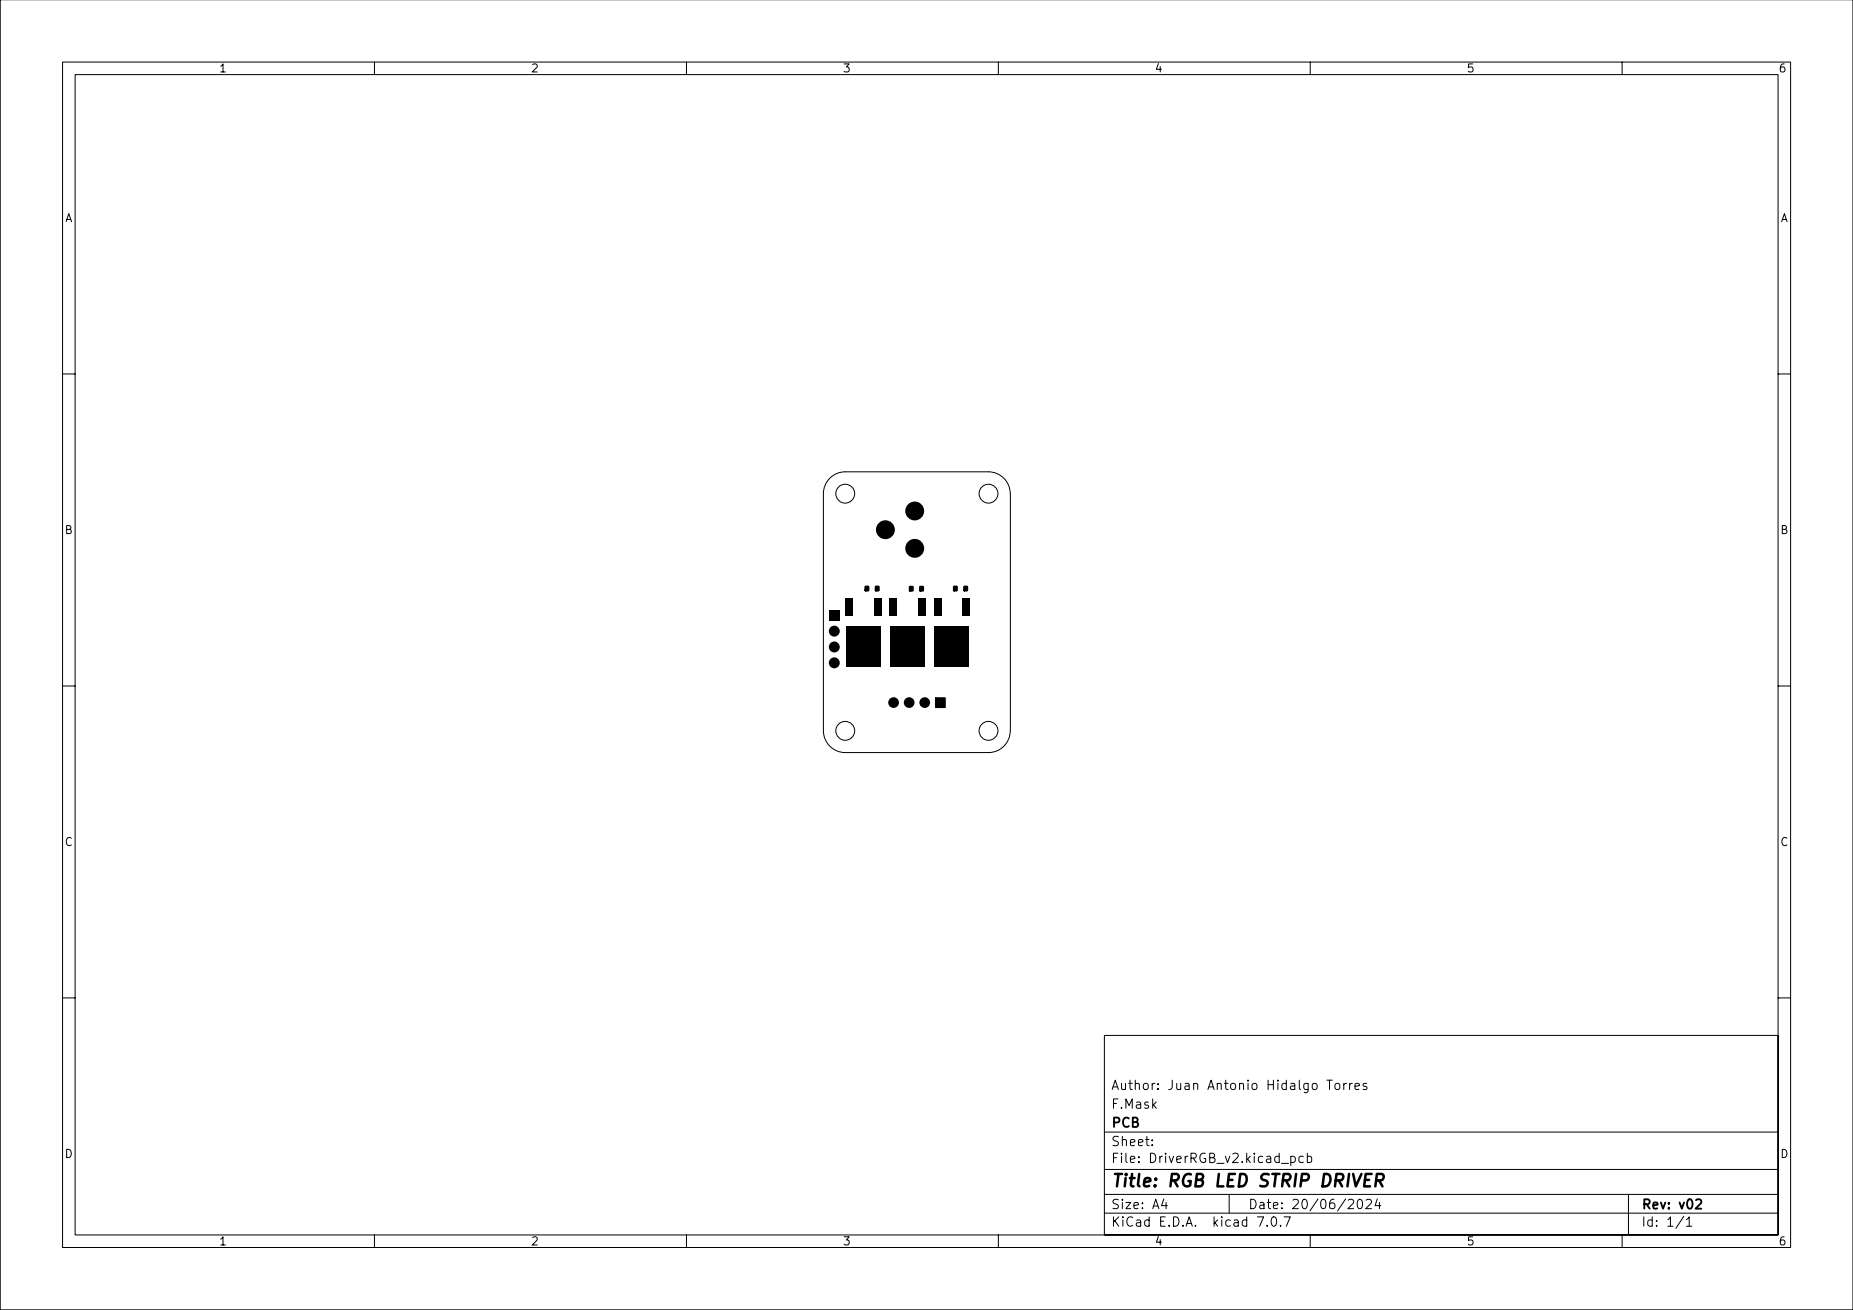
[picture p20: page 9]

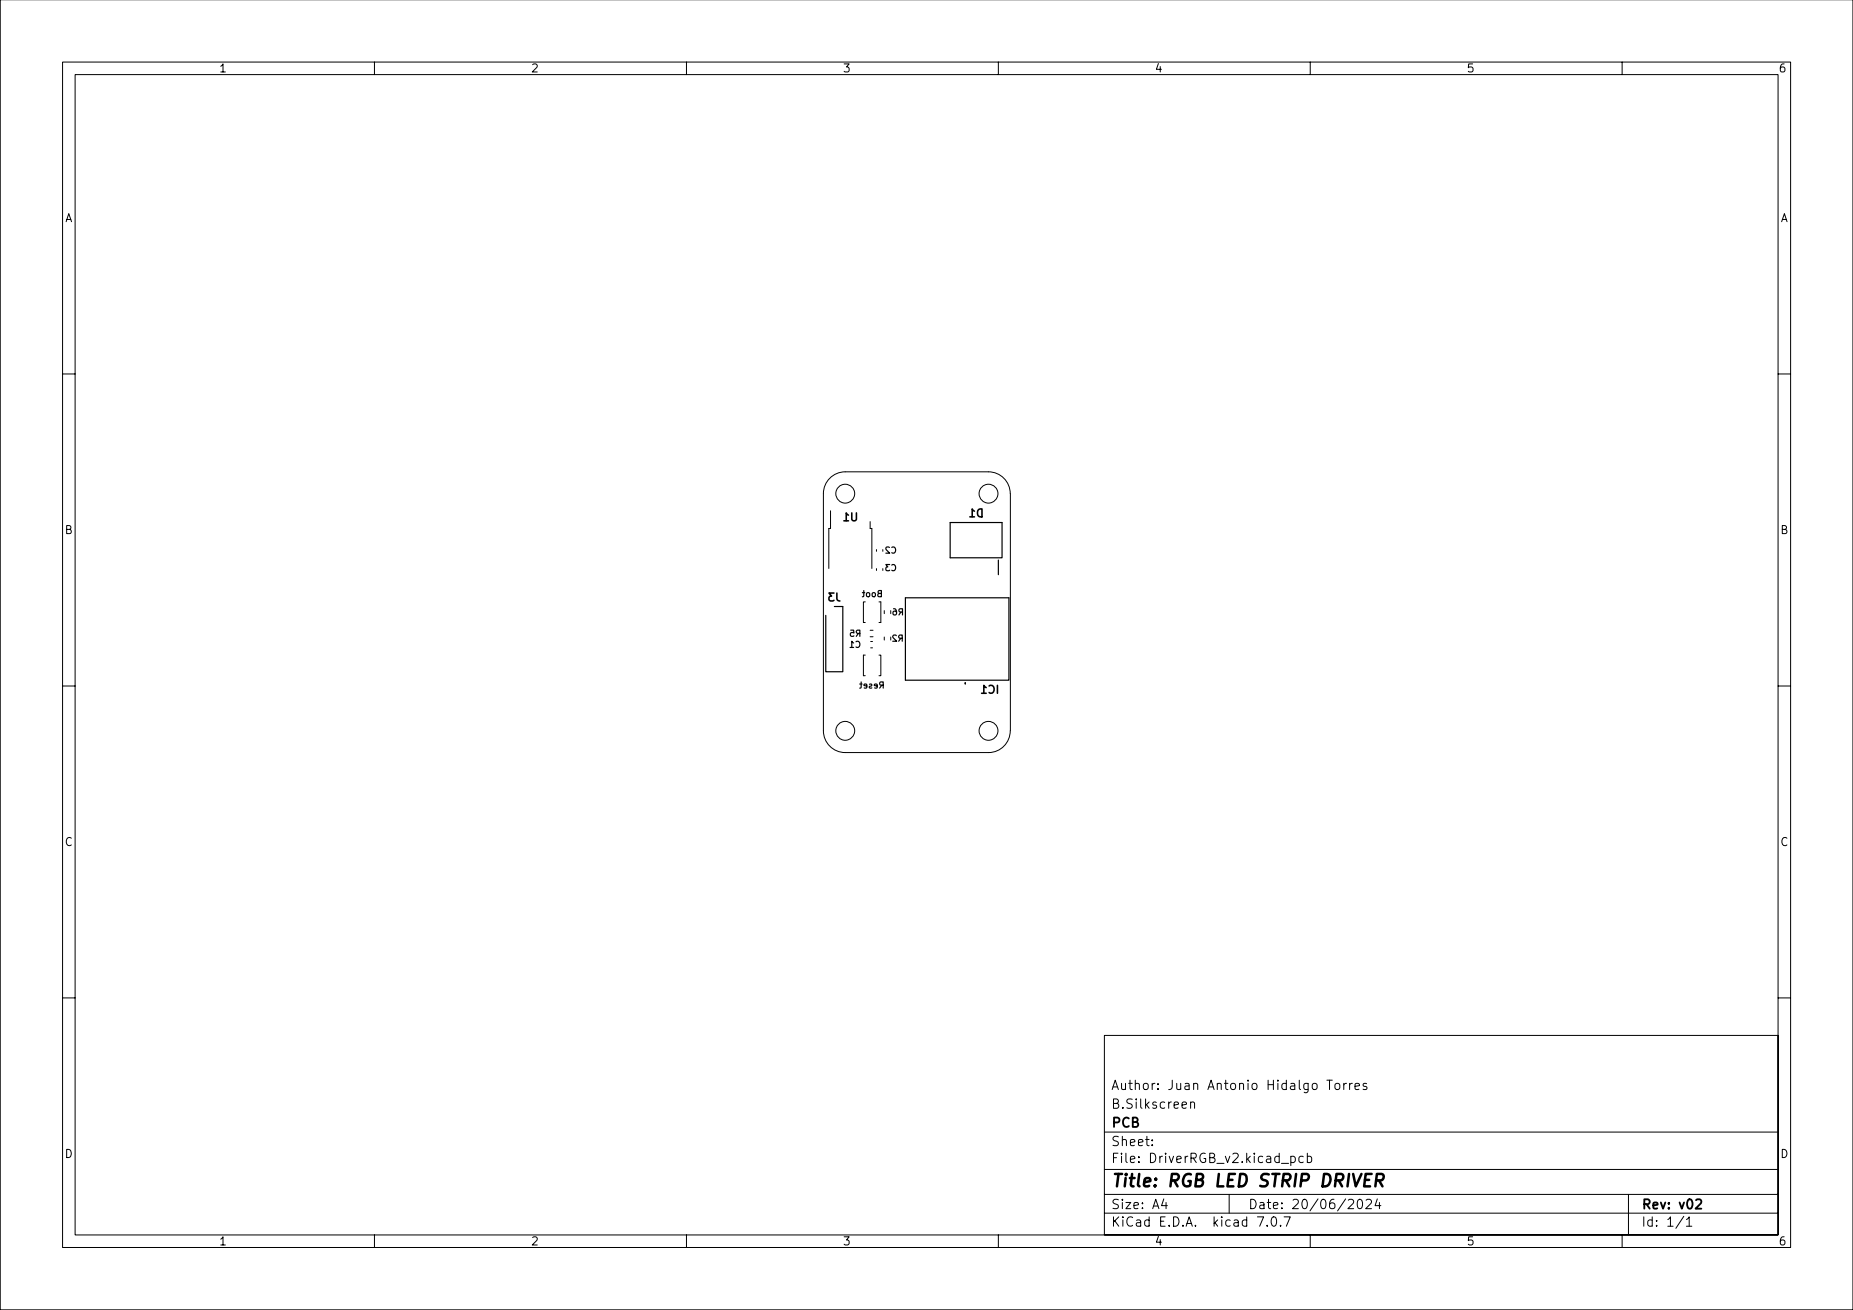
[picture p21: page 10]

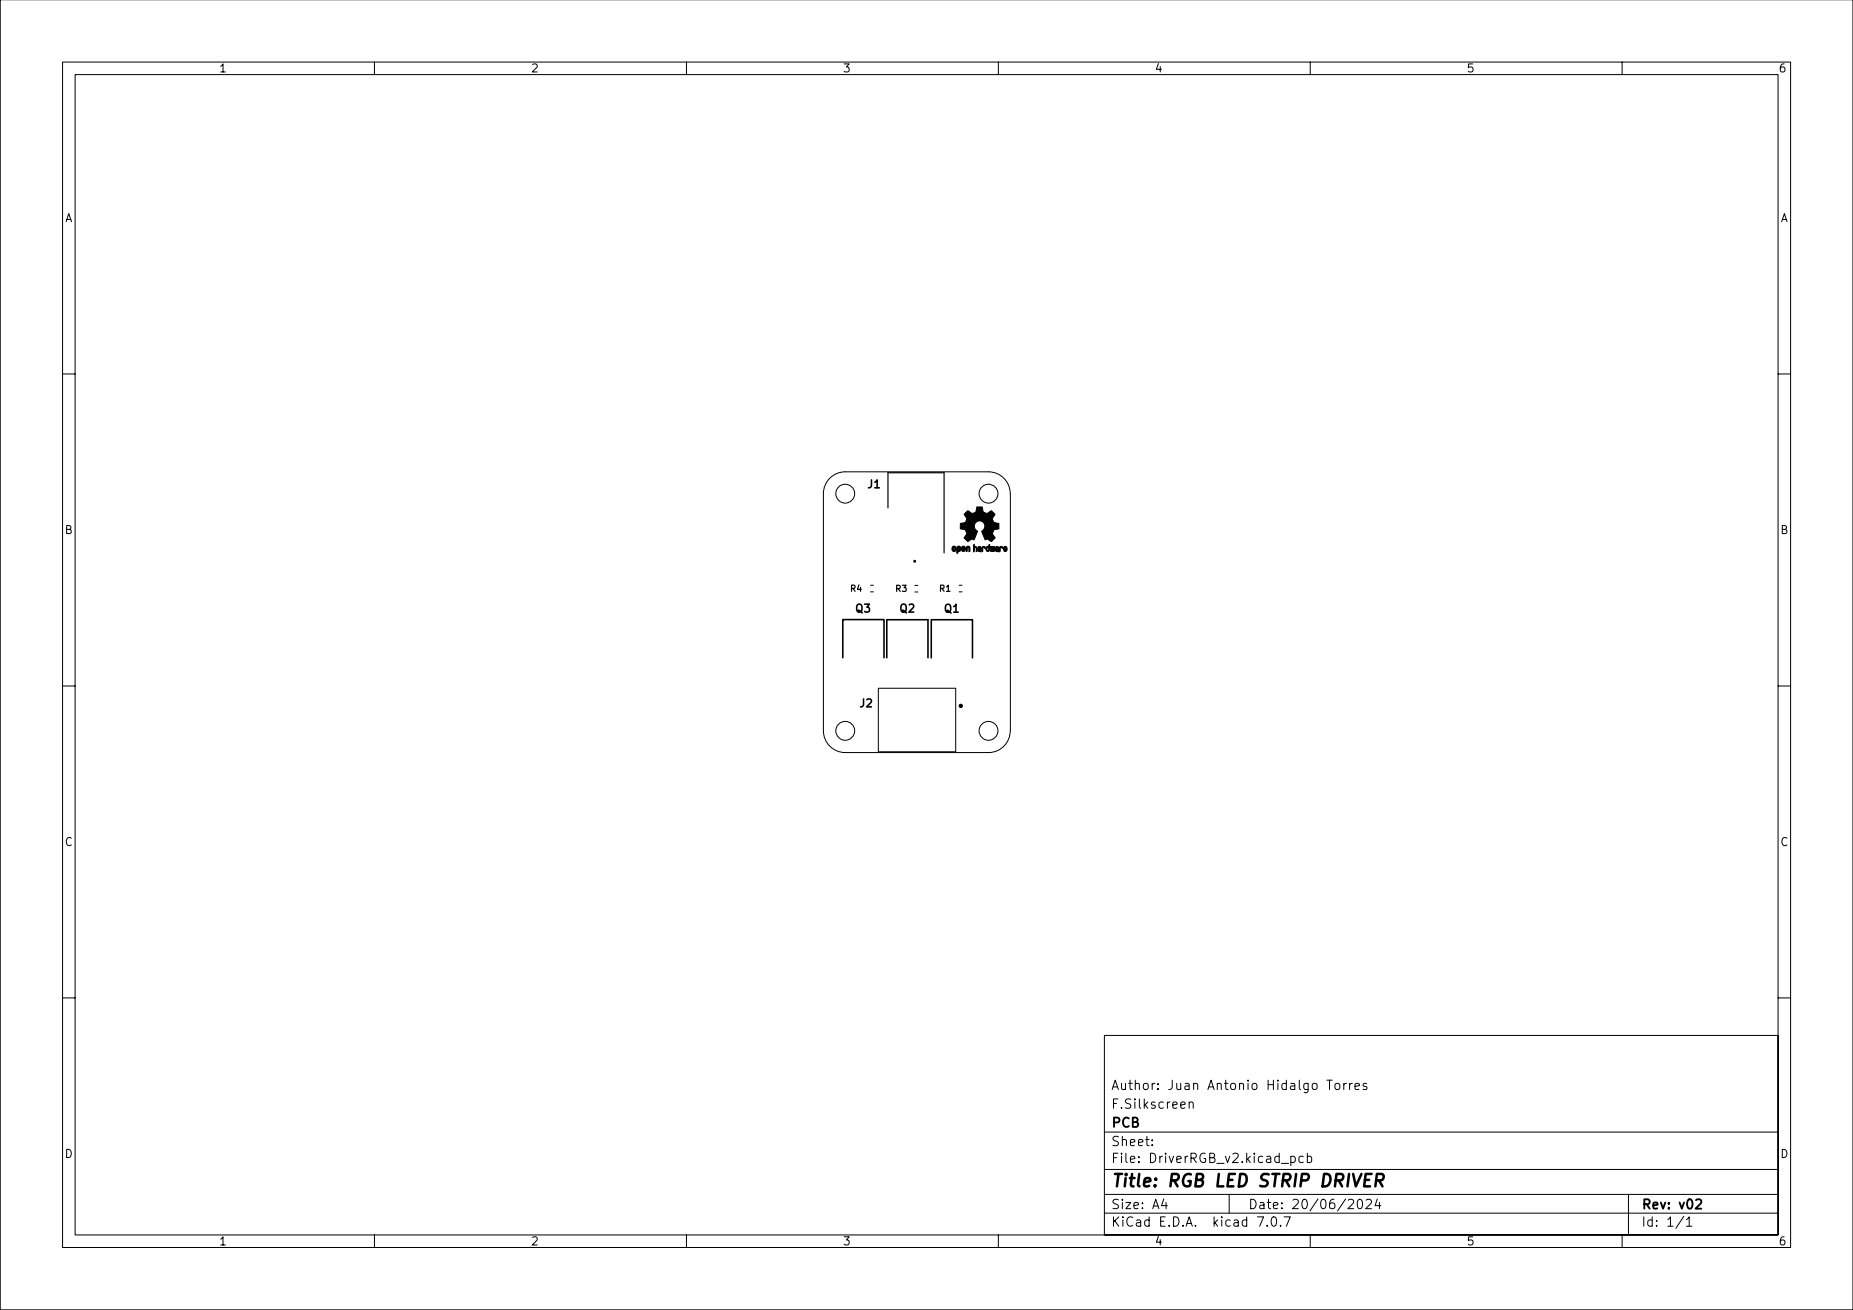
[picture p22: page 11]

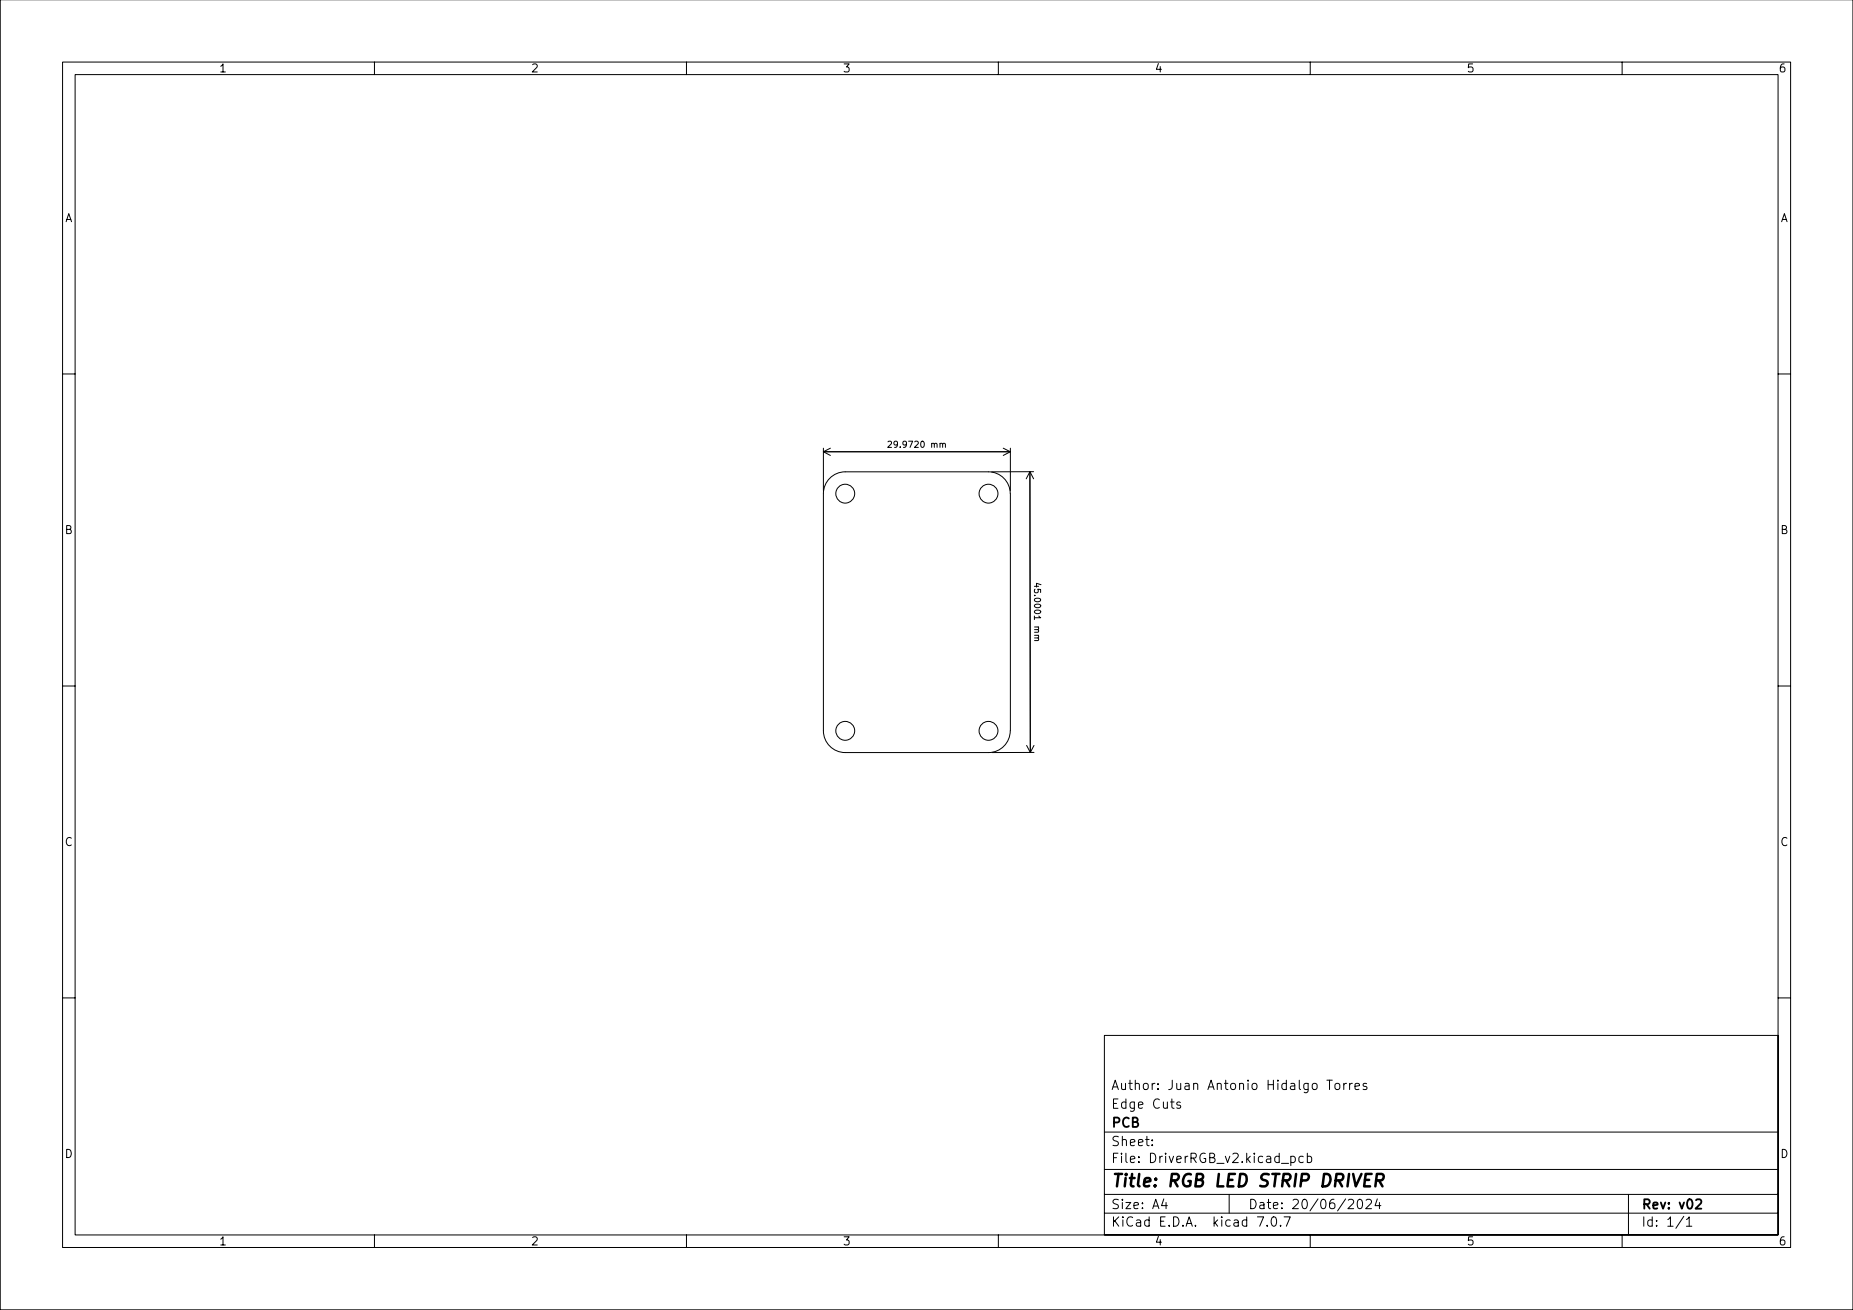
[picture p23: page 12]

Drill; Map:; holes)












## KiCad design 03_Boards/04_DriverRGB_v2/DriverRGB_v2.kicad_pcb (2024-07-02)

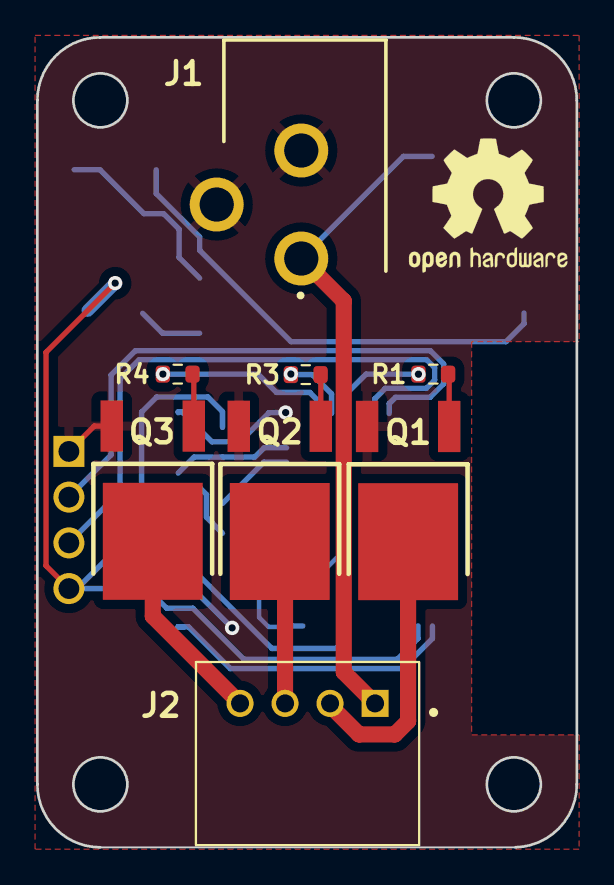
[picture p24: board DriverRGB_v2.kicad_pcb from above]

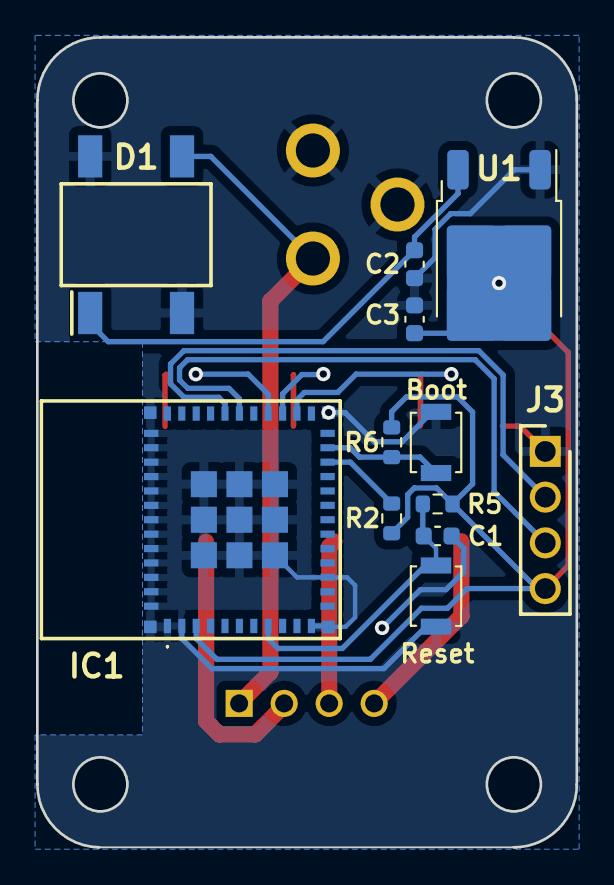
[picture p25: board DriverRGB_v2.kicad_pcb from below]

Board: 2 copper layers, 30.0 x 45.0 mm, 20 parts (12 on the bottom side), 18 nets.

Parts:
C1: 100nF; C_0603_1608Metric
C2, C3: 1uF; C_0603_1608Metric
D1: DF04S-E3; DF04S-E3_77
IC1: ESP32-C6-MINI-1-N4
J1: PJ-102A; PJ-102AH
J2: S4B-XH-A_LF__SN_
J3: 61300411121
Q1, Q2, Q3: FDD8880
R1, R2, R3, R4, R5, R6: 10kOhm; R_0603_1608Metric
S1: Reset; SW_SPST_B3U-1000P
S2: Boot; SW_SPST_B3U-1000P
U1: AMS1117CD-3.3; TO-252-2

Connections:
BLUE_OUT-: J2.4, Q3.3 (D)
EN: C1.1, IC1.8 (EN), R5.2, S1.2
GND: C1.2, C2.2, C3.2, D1.2 (-), D1.4, IC1.1 (GND_1), IC1.2 (GND_2), IC1.11 (GND_3), IC1.14 (GND_4), IC1.36 (GND_5), IC1.37 (GND_6), IC1.38 (GND_7), IC1.39 (GND_8), IC1.40 (GND_9), IC1.41 (GND_10), IC1.42 (GND_11), IC1.43 (GND_12), IC1.44 (GND_13), IC1.45 (GND_14), IC1.46 (GND_15), IC1.47 (GND_16), IC1.48 (GND_17), IC1.49 (GND_18), IC1.50 (GND_19), IC1.51 (GND_20), IC1.52 (GND_21), IC1.53 (GND_22), IC1.54 (GND_23), IC1.55 (GND_24), IC1.56 (GND_25), IC1.57 (GND_26), IC1.58 (GND_27), IC1.59 (GND_28), IC1.60 (GND_29), IC1.61 (GND_30), J1.2, J1.3, J3.1, Q1.2 (S), Q2.2 (S), Q3.2 (S), S1.1, S2.1, U1.1 (GND)
GREEN_OUT-: J2.3, Q2.3 (D)
IO9: IC1.23 (IO9), R6.2, S2.2
unnamed: C2.1, D1.1 (+), U1.3 (VI)
unnamed: IC1.22 (IO8), R2.2
unnamed: Q1.1 (G), R1.2
unnamed: Q2.1 (G), R3.2
unnamed: Q3.1 (G), R4.2
PWM_BLUE: IC1.26 (IO20), R4.1
PWM_GREEN: IC1.27 (IO21), R3.1
PWM_RED: IC1.28 (IO22), R1.1
PWR_IN: D1.3, J1.1, J2.1
RED_OUT-: J2.2, Q1.3 (D)
RX: IC1.30 (RXD0), J3.3
TX: IC1.31 (TXD0), J3.2
VDD: C3.1, IC1.3 (3V3), J3.4, R2.1, R5.1, R6.1, U1.2 (VO)

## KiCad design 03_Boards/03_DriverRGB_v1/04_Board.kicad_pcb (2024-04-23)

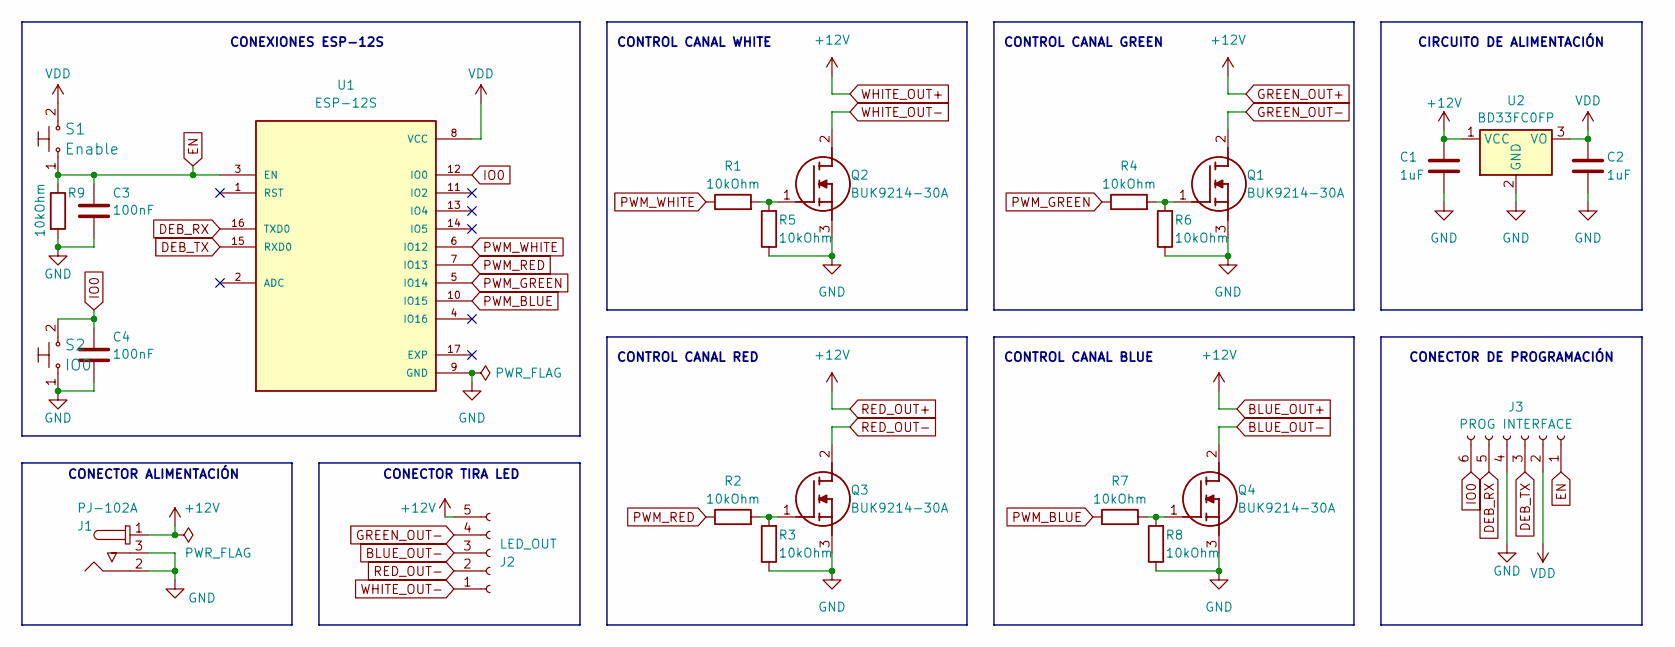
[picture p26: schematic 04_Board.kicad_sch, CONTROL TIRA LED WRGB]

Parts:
C1, C2: 1uF; C_1206_3216Metric
C3, C4: 100nF; C_1206_3216Metric
J1: PJ-102A; PJ-102AH; MPN PJ-102A; Digi-Key_PN CP-102A-ND
J2: LED_OUT; TerminalBlock_Phoenix_MKDS-1,5-5_1x05_P5.00mm_Horizontal
J3: PROG INTERFACE; PROG_INTERFACE
Q1, Q2, Q3, Q4: BUK9214-30A; BUK921430A118; Mouser Part Number 771-BUK9214-30A,118
R1, R2, R3, R4, R5, R6, R7, R8, R9: 10kOhm; R_1206_3216Metric
S1: Enable; SW_SPST_B3U-1000P; MPN B3U-1000P; Digi-Key_PN SW1020CT-ND
S2: IO0; SW_SPST_B3U-1000P; MPN B3U-1000P; Digi-Key_PN SW1020CT-ND
U1: ESP-12S; PARTREV V1.1
U2: BD33FC0FP; TO-252-2

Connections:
BLUE_OUT+: C1.1, J1.1, J2.5, U2.1 (VCC)
BLUE_OUT-: J2.3, Q4.2 (D)
DEB_RX: J3.5, U1.16 (TXD0)
DEB_TX: J3.3, U1.15 (RXD0)
EN: C3.1, J3.1, R9.1, S1.1, U1.3 (EN)
GND: C1.2, C2.2, C3.2, C4.2, J1.2, J1.3, J3.4, Q1.3 (S), Q2.3 (S), Q3.3 (S), Q4.3 (S), R3.1, R5.1, R6.1, R8.1, R9.2, S2.1, U1.9 (GND), U2.2 (GND)
GREEN_OUT-: J2.4, Q1.2 (D)
IO0: C4.1, J3.6, S2.2, U1.12 (IO0)
unnamed: Q1.1 (G), R4.2, R6.2
unnamed: Q2.1 (G), R1.2, R5.2
unnamed: Q3.1 (G), R2.2, R3.2
unnamed: Q4.1 (G), R7.2, R8.2
PWM_BLUE: R7.1, U1.10 (IO15)
PWM_GREEN: R4.1, U1.5 (IO14)
PWM_RED: R2.1, U1.7 (IO13)
PWM_WHITE: R1.1, U1.6 (IO12)
RED_OUT-: J2.2, Q3.2 (D)
VDD: C2.1, J3.2, S1.2, U1.8 (VCC), U2.3 (VO)
WHITE_OUT-: J2.1, Q2.2 (D)

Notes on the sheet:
CONECTOR DE PROGRAMACIÓN
CONTROL CANAL BLUE
CONEXIONES ESP-12S
CONECTOR ALIMENTACIÓN
CONTROL CANAL GREEN
CONTROL CANAL RED
CONECTOR TIRA LED
CIRCUITO DE ALIMENTACIÓN
CONTROL CANAL WHITE

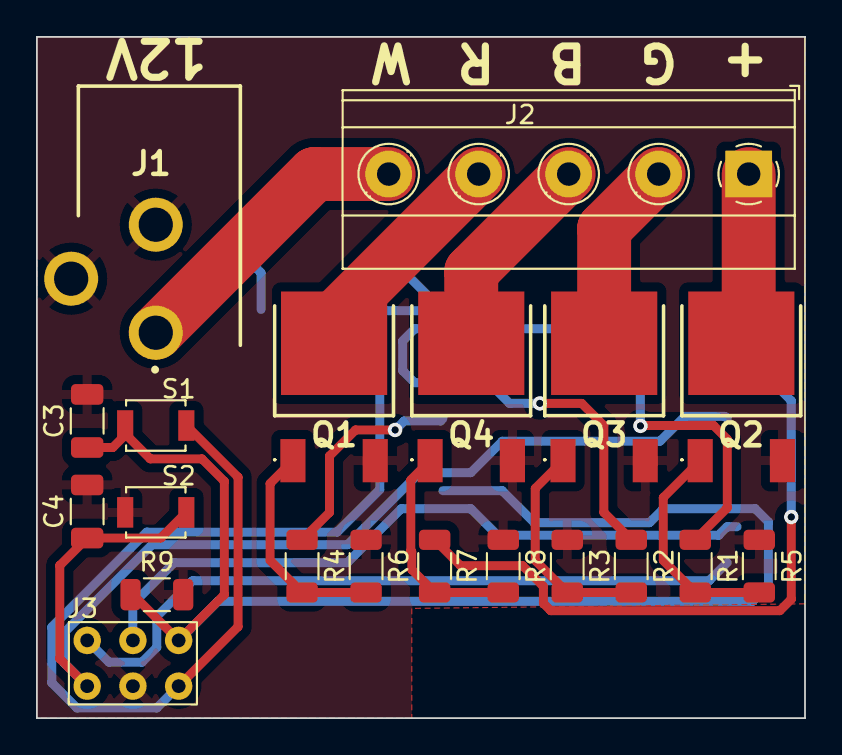
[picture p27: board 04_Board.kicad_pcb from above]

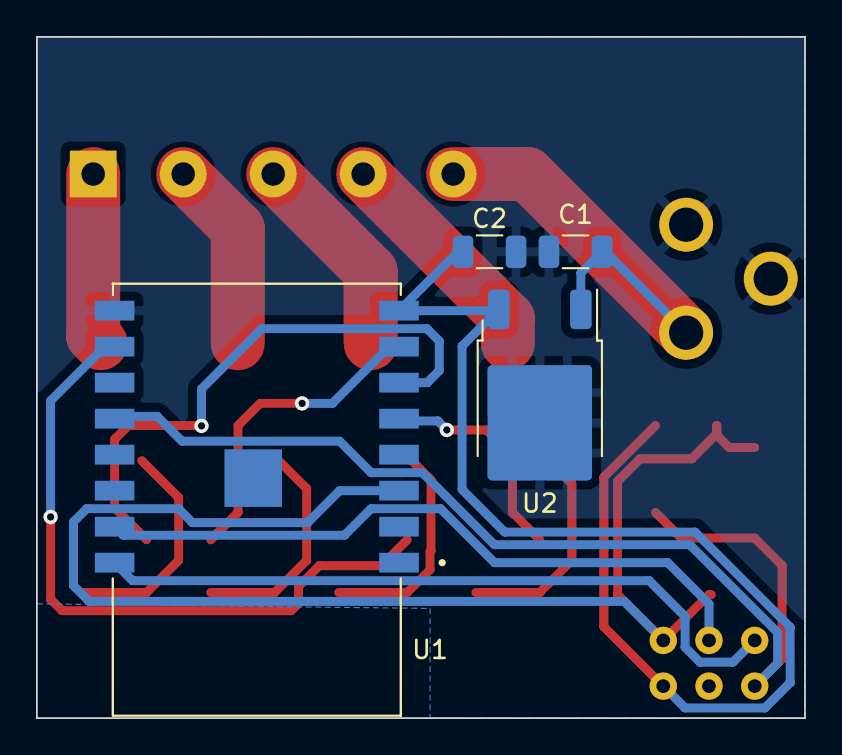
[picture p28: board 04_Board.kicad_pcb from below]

Board: 2 copper layers, 42.7 x 37.8 mm, 24 parts (4 on the bottom side), 19 nets.

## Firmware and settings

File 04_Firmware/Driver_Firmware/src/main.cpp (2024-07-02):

// RGB LED STRIP DRIVER FIRMWARE.

// Libraries.
#include <Arduino.h>
#include <WiFi.h>
#include <SinricPro.h>
#include <SinricProLight.h>
#include <map>

// Global constants.
const char wifi_ssid[]  = "YOUR-WIFI-SSID";
const char wifi_pass[]  = "YOUR-WIFI-PASS";
const char app_key[]    = "YOUR-APPKEY";
const char app_secret[] = "YOUR-APPSECRET";
const char light_id[]   = "YOUR-DEVICEID";
const int baud_rate     = 115200;           // Baudrate to serial log
const int blue_pin      = 20;               // PIN for BLUE Mosfet
const int red_pin       = 22;               // PIN for RED Mosfet
const int green_pin     = 21;               // PIN for GREEN Mosfet
SinricProLight& myLight = SinricPro[light_id];  // SinricProLight device.

// Global variables.
struct Color {
    uint8_t r;
    uint8_t g;
    uint8_t b;
};

using ColorTemperatures = std::map<uint16_t, Color>; // Colortemperature lookup table.
ColorTemperatures colorTemperatures{
    //   {Temperature value, {color r, g, b}}
    {2000, {255, 138, 18}},
    {2200, {255, 147, 44}},
    {2700, {255, 169, 87}},
    {3000, {255, 180, 107}},
    {4000, {255, 209, 163}},
    {5000, {255, 228, 206}},
    {5500, {255, 236, 224}},
    {6000, {255, 243, 239}},
    {6500, {255, 249, 253}},
    {7000, {245, 243, 255}},
    {7500, {235, 238, 255}},
    {9000, {214, 225, 255}}};

struct DeviceState {                                   // Stores current device state with following initial values:
    bool  powerState       = false;                    // initial state is off
    Color color            = colorTemperatures[9000];  // color is set to white (9000k)
    int   colorTemperature = 9000;                     // color temperature is set to 9000k
    int   brightness       = 100;                      // brightness is set to 100
} device_state;


// Functions.
void setStripe() {
    int rValue = map(device_state.color.r * device_state.brightness, 0, 255 * 100, 0, 1023);  // Calculate red value and map between 0 and 1023 for analogWrite.
    int gValue = map(device_state.color.g * device_state.brightness, 0, 255 * 100, 0, 1023);  // Calculate green value and map between 0 and 1023 for analogWrite.
    int bValue = map(device_state.color.b * device_state.brightness, 0, 255 * 100, 0, 1023);  // Calculate blue value and map between 0 and 1023 for analogWrite.

    if (device_state.powerState == false) {  // Turn off?.
        digitalWrite(red_pin, LOW);          // Set.
        digitalWrite(green_pin, LOW);        // Mosfets.
        digitalWrite(blue_pin, LOW);         // Low.
    } 
    else {
        analogWrite(red_pin, rValue);       // Write red value to pin.
        analogWrite(green_pin, gValue);     // Write green value to pin.
        analogWrite(blue_pin, bValue);      // Write blue value to pin.
    }
}

bool onPowerState(const String& deviceId, bool& state) {
    device_state.powerState = state;  // Store the new power state.
    setStripe();                      // Update the mosfets.
    return true;
}

bool onBrightness(const String& deviceId, int& brightness) {
    device_state.brightness = brightness;  // Store new brightness level.
    setStripe();                           // Spdate the mosfets.
    return true;
}

bool onAdjustBrightness(const String& deviceId, int& brightnessDelta) {
    device_state.brightness += brightnessDelta;  // Calculate and store new absolute brightness.
    brightnessDelta = device_state.brightness;   // Return absolute brightness.
    setStripe();                                 // Update the mosfets.
    return true;
}

bool onColor(const String& deviceId, byte& r, byte& g, byte& b) {
    device_state.color.r = r;  // Store new red value.
    device_state.color.g = g;  // Store new green value.
    device_state.color.b = b;  // Store new blue value.
    setStripe();               // Update the mosfets.
    return true;
}

bool onColorTemperature(const String& deviceId, int& colorTemperature) {
    device_state.color            = colorTemperatures[colorTemperature];  // Set rgb values from corresponding colortemperauture.
    device_state.colorTemperature = colorTemperature;                     // Store the current color temperature.
    setStripe();                                                          // Update the mosfets.
    return true;
}

bool onIncreaseColorTemperature(const String& devceId, int& colorTemperature) {
    auto current = colorTemperatures.find(device_state.colorTemperature);  // Get current entry from colorTemperature map.
    auto next    = std::next(current);                                     // Get next element.
    if (next == colorTemperatures.end()) next = current;                   // Prevent past last element.
    device_state.color            = next->second;                          // Set color.
    device_state.colorTemperature = next->first;                           // Set colorTemperature.
    colorTemperature              = device_state.colorTemperature;         // Return new colorTemperature.
    setStripe();
    return true;
}

bool onDecreaseColorTemperature(const String& devceId, int& colorTemperature) {
    auto current = colorTemperatures.find(device_state.colorTemperature);  // Get current entry from colorTemperature map.
    auto next    = std::prev(current);                                     // Get previous element.
    if (next == colorTemperatures.end()) next = current;                   // Prevent before first element.
    device_state.color            = next->second;                          // Set color.
    device_state.colorTemperature = next->first;                           // Set colorTemperature.
    colorTemperature              = device_state.colorTemperature;         // Return new colorTemperature.
    setStripe();
    return true;
}

void setupWiFi() {
    Serial.printf("WiFi: connecting ...");
    WiFi.setSleep(false); 
    WiFi.setAutoReconnect(true);
    WiFi.begin(wifi_ssid,wifi_pass); 
    while (WiFi.status() != WL_CONNECTED) {
        Serial.printf(".");
        delay(250);
    }
    Serial.printf("connected\r\nIP is %s\r\n", WiFi.localIP().toString().c_str());
}

void setupSinricPro() {
    myLight.onPowerState(onPowerState);                              // Assign onPowerState callback.
    myLight.onBrightness(onBrightness);                              // Assign onBrightness callback.
    myLight.onAdjustBrightness(onAdjustBrightness);                  // Assign onAdjustBrightness callback.
    myLight.onColor(onColor);                                        // Assign onColor callback.
    myLight.onColorTemperature(onColorTemperature);                  // Assign onColorTemperature callback.
    myLight.onDecreaseColorTemperature(onDecreaseColorTemperature);  // Assign onDecreaseColorTemperature callback.
    myLight.onIncreaseColorTemperature(onIncreaseColorTemperature);  // Assign onIncreaseColorTemperature callback.

    SinricPro.begin(app_key,app_secret);  // start SinricPro
}


// Configuration.
void setup() {

    // UART configuration.
    Serial.begin(baud_rate);
    Serial.println("Serial communication started ...");
    
    // Pin configuration.
    pinMode(red_pin,OUTPUT);    // Set red-mosfet pin as output.
    pinMode(green_pin,OUTPUT);  // Set green-mosfet pin as output.
    pinMode(blue_pin,OUTPUT);   // Set blue-mosfet pin as output.

    // Wi-Fi connection.
    setupWiFi();

    // Sinric Pro configuration.
    setupSinricPro();
}

// Loop.
void loop() {
    SinricPro.handle();
}

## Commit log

2024-04-23 Driver case
    [Driver_Case_Bottom.stl, Driver_Case_Top.stl]
2024-06-18 Rediseño del esquemático del PCB
    [20021121-00006C1LF.step, 61300411121.stp, BUK9214-30A,118.stp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]
2024-06-20 Board desing v2
    [BoM.xlsx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]
2024-07-02 Firmware update for esp32 support
